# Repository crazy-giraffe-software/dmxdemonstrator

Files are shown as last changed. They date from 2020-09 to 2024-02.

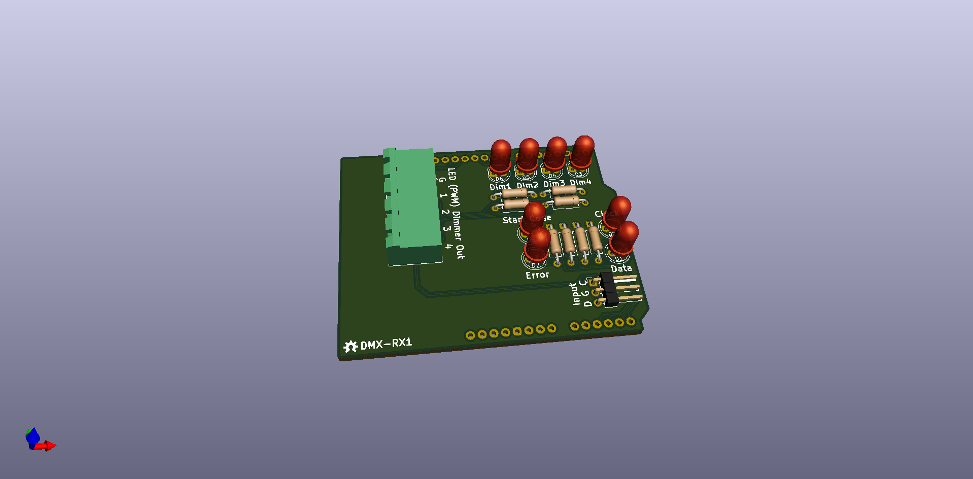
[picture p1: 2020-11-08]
hardware/receiver/receiver.png

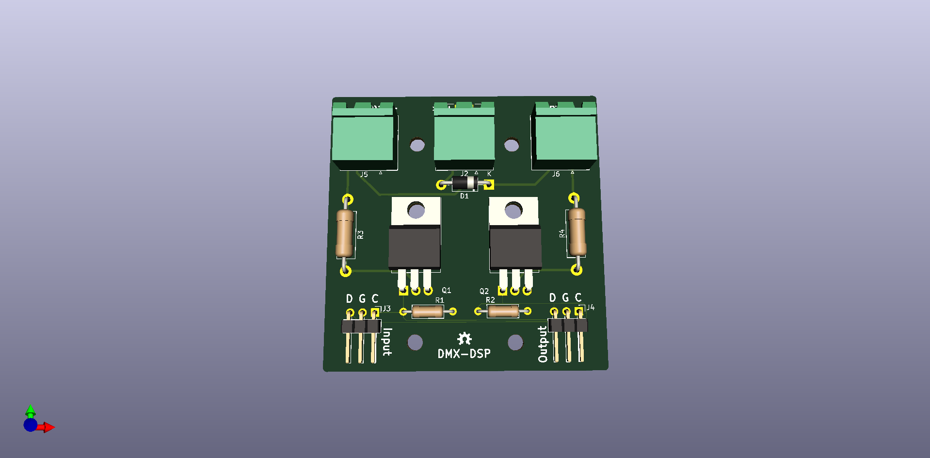
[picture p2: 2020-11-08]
hardware/display-pro/display-pro.png

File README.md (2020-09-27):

# DMX Demonstrator

## Background

When I was in grad school, I was challenged by my technical theater professor to create a device to demonstrate DMX. What we devised was a transmitter receiver pair with 4 controls and 4 dimmers and the pair was linked by a three-wire cable. The transmitter had a fixed clock that could run at reasonable fast, xxkHz, and a variable clock that could be adjusted down to 0.5 hZ. By switching back and forth, you could toggle between "real-time" updates and a slow pace that can be used to see each bit on the wire. We then built a lecture around how the data was digitized, serialized, de-serialized, and converted back to analog to control the dimmers.

The device was built and did function even though it failed to follow a number of best engineering practices. At that time, we didn't have [GitHub](https://github.com/) and [Tindie](https://www.tindie.com/) so sharing the project was by word-of-mouth and email; yes, we did have [email](https://en.wikipedia.org/wiki/Email). Only one other group considered building a replica but alas they never did. The device was built only once and transported to a USITT conference in Las Vegas, where the EPROM failed and we had nothing to show except a presentation. Only a handful of students at my school ever got to see it function.

That was 25 years ago. For it's anniversary, I've decided to revive the project and build 2 new implementations. The first is based on Arduino for a cheap but functional version of the project that is unlikely to fail or break the bank. The second is an updated recreation of the original using today's available hardware but without deviating from the original TTL-based design, i.e. no microprocessors or microcontrollers. I'll admit this last one is really just for me because I love designing electronics, drawing schematics, laying out PCBs, and assembling electronics.

## Hardware

In the hardware folder, you'll find a series of designs:

- transmitter - An arduino-based transmitter.
- receiver - An arduino-based receiver.
- control-pro - A controller built to work with either transmitter or transmitter-pro.
- display-pro - An external large-format display for data and clock signals.

## Firmware/Software

As you would expect, the Arduino-based version is implemented mostly in software. The Sketch files for both transmitter and receiver are in the software folder and ready to upload to an Arduino UNO R3. The sketch and hardware will likely work with any Arduino-compatible board.

## Monitoring

All informational output is sent to via the serial port for easy display on a computer. However, the clock and serial data are displayed via LEDs to visualize the serial data.

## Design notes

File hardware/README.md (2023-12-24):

# DMX Demonstrator Hardware

## Overview

The DMX Demonstrator hardware folder contains various transmitters, receivers, and modules which all for the control of brightness of 4 channels of dimming.

## Status

Each hardware folder will contain a readme explaining the details of the component and it's status. The following is a definition of some common status:

- 

The _verified_ badge indicates that the component has been built and tested for use with the DMX Demonstrator family and is safe to build.

- 

The _testing_ badge indicates that the component has completed the design and prototype phase and being verified for use with the DMX Demonstrator family. It usually is assigned to a component revision for which the previous version is _verified_.

- 

The _prototype_ badge indicates that the component has completed the design phase and is being built and tested for use with the DMX Demonstrator family.

- 

The _design_ badge indicates that the component is still being design. has completed the design phase.

## Compatibility

For the components which connect to an Arduino, the readme provides a list of known compatible Arduino platforms. The DMX Demonstrator family will likely work with most Arduino boards, real or clones, but if you are having an
[issue](https://github.com/crazy-giraffe-software/dmxdemonstrator/issues) with a particular board, open an issue to ask for verification. Please provide as much detail on the board and where is was obtained as possible.
Most compatibility issues are resolved by updating the software and do not require hardware revisions.

The following is a definition of some compatibilities:

- 

The _verified_ badge indicates that the component has been built and tested for the specific Arduino board.

- 

The _testing_ badge indicates that the component is being tested to determine if it is compatible with the specific Arduino board.

- 

The _research_ badge indicates that the component is being researched to determine if it is compatible with the specific Arduino board.

- 

The _incompatible_ badge indicates that the component is not compatible for the specific Arduino board.

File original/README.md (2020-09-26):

# DMX Demonstrator

## Background

When I was in grad school, I was challenged by my technical theater professor to create a device to demonstrate DMX. What we devised was a transmitter receiver pair with 4 controls and 4 dimmers and the pair was linked by a three-wire cable. The transmitter had a fixed clock that could run at reasonable fast, xxkHz, and a variable clock that could be adjusted down to 0.5 hZ. By switching back and forth, you could toggle between "real-time" updates and a slow pace that can be used to see each bit on the wire. We then built a lecture around how the data was digitized, serialized, de-serialized, and converted back to analog to control the dimmers.

The device was built and did function even though it failed to follow a number of best engineering practices. At that time, we didn't have GitHub and Tindie so sharing the project was by word-of-mouth and email; yes, we did have email. Only one other group considered building a replica but alas they never did. The device was built only once and transported to a USITT conference in Las Vegas, where the EPROM failed and we had nothing to show except a presentation. Only a handful of students at my school ever got to see it function.

That was 25 years ago. For it's anniversary, I've decided to revive the project and build 2 new implementations. The first is based on Arduino for a cheap but functional version of the project that is unlikely to fail or break the bank. The second is an updated recreation of the original using today's available hardware but without deviating from the original TTL-based design, i.e. no microprocessors or microcontrollers. I'll admit this last one is really just for me because I love designing electronics, drawing schematics, laying out PCBs, and assembling electronics.

## Artifacts

These are the original digital artifacts we created in 1994 for the DMX Demonstrator. The are preserved here for posterity.

The schematics were original drawn in Autocad but the files have been lost. The paper copy was not lost, the PDFs are a scan of those documents.

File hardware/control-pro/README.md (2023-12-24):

# DMX Demonstrator Control Pro  (DMX-CP*)



## Overview

The Control Pro is built to work with either transmitter or transmitter-retro. When used with an Arduino, an additional board, the Transmitter IO Interface (DMX-TX2), is required to connect the Control Pro to the Arduino. The transmitter software automatically detects whether DMX-TX1, the standard transmitter, or DMX-TX2, the Transmitter IO Interface, is connected.

The Control Pro is designed so that a series of components are sandwiched between 2 circuit boards. As a result, the heights of the components are fairly sensitive in order to make things line up nicely. The DMX-CPDB and DMX-CPCB boards contains all the parts and are the bottom of the sandwich, the DMX-CPDF and DMX-CPCB are the faceplate, i.e. the tops of the sandwich. If you are wondering why there are 4 total boards, see _PCB->Quality vs Price_ below.

## Online parts list

Sparkfun offers some, but not all, of the components required for the Control Pro. For the parts they can supply, you can find a parts lists [here](https://www.sparkfun.com/wish_lists/160543).

Additionally, you'll need some parts from the common parts lists as well. You can find the common parts list [here](https://www.sparkfun.com/wish_lists/160406). The rainbow LED pack include 2 sets of LED so if you are building more than 2 transmitters or receivers, make sure to buy 1 pack for every 2 transmitters/receivers.

## PCB

You can order the PCBs from [OHS Park](https://oshpark.com/):

- [Clock Control: DMX-CPCB, Rev 1.3](https://oshpark.com/shared_projects/llBuRZd8)
- [Clock Faceplate: DMX-CPCF, Rev 1.3](https://oshpark.com/shared_projects/S9LARHyr)
- [Dimmer Control: DMX-CPDB, Rev 1.3](https://oshpark.com/shared_projects/O76YiRT8)
- [Dimmer Faceplate: DMX-CPDF, Rev 1.3](https://oshpark.com/shared_projects/bZqKigQF)

### Quality vs Price

While it is counterintuitive (and in some cases wrong), splitting the clock controls and dimmer controls on different boards reduces cost. Many PCB manufacturers offer a fixed cost for board smaller than a certain size. These boards are 100mm x 100mm, which is standard max size for many low-cost board manufacturers. Others like OHSPark charge by the square inch and therefore the separate control approach is more expensive. Revision 1.1 was a single set of boards 180mm x 90mm for which OHSPark charges about $250US for 3 copies of both boards. Revision 1.3 is more expensive from OHSPark but can be as cheap as $20US for 5 copies of all 4 boards from cheaper board manufacturers. Yes, there is a quality BIG difference between those prices but the cheaper board will work just fine.

OHSPark offers really great quality at great prices, they are easy to work with, manufacture 100% in the US, and their support is excellent. I use OHSPark for most things I build, expect when the cost is super high. Lower cost boards can be had but if you specify the same quality board OHSPark offers, you will find OHSPark to be competitive. Yes, the links above are for the more expensive OHSPark board for the reason I listed above plus ease of use: You can upload the file directly from Kicad and they can produce a board. Better yet, they will save that board for others to order. They make it so easy to order for a project like this it's silly not to use them.

I offer this opinion freely and do not receive any compensation from OHSPark.

## Parts

The Control Pro is designed so that a series of components are sandwiched between 2 circuit boards. As a result, the heights of the components are fairly sensitive in order to make things line up nicely. Here are the parts for which I designed. The DMX-CPDB and DMX-CPCB boards contains all the parts and are the bottom of the sandwich, the DMX-CPDF and DMX-CPCB are the faceplate, i.e. the tops of the sandwich. If you are wondering why there are 4 total boards, see _PCB->Quality vs Price_.

### Slider Potentiometers

Getting a potentiometer and knob combo that would work with the rest of the components was probably the hardest part of part selection.
I had initially ordered some 60mm 10k sliders from SparkFun with matching knobs and they measures about 25mm from the bottom of the
part to the bottom of the knob, which is way too tall for the other components! I landed on a combination of Bourns PTA Series
sliders with an knob available from Sparkfun (and others). During this process, I opted for a 45mm travel to keep the board smaller/cheaper
while still offering good mechanical resolution. The specific parts I designed for are:

- Dimmer Sliders: Bournes PTA4543-2015DPB103, quantity 4:
  - [Data sheet](https://www.mouser.com/datasheet/2/54/pta-778345.pdf)
  - [Digikey PTA4543-2015DPB103-ND](https://www.digikey.com/products/en?keywords=PTA4543-2015DPB103-ND)
  - [Mouser 652-PTA45432015DPB10](https://www.mouser.com/ProductDetail/Bourns/PTA4543-2015DPB103?qs=U%2FacTlguYxbmwS%2FtylIWJw%3D%3D)
- Knobs: Eagle 450-3051, quantity 4:
  - [Datasheet](https://www.mouser.com/datasheet/2/209/EPD-200140-1171100.pdf)
  - [Mouser 450-3051](https://www.mouser.com/ProductDetail/Eagle-Plastic-Devices/450-3051?qs=hTs5c5NaUrTeABpuQnP9ug%3D%3D)
  - [Sparkfun COM-09120](https://www.sparkfun.com/products/9120) - Included in online parts list

### Toggle Switches

Just about any miniature toggle switch will do, many manufacturers make a switch in a similar size. I specifically used the E-Switch Series 100 Miniature Toggle Switches, specifically:

- Clock Speed: E-Switch 100DP3T1B1M1QEH, quantity 1:
  - [Datasheet](https://sten-eswitch-13110800-production.s3.amazonaws.com/system/asset/product_line/data_sheet/129/100.pdf)
  - [Digikey EG2413-ND](https://www.digikey.com/products/en?keywords=100DP3T1B1M1QEH)
  - [Mouser 612-100-H1111](https://www.mouser.com/ProductDetail/E-Switch/100DP3T1B1M1QEH?qs=g8hxKYs5b3yy1L1GZVrx5w%3D%3D)
- Clock Step: E-Switch 100SP2T1B1M1QEH, quantity 1:
  - [Datasheet](https://sten-eswitch-13110800-production.s3.amazonaws.com/system/asset/product_line/data_sheet/129/100.pdf)
  - [Digikey EG2373-ND](https://www.digikey.com/product-detail/en/e-switch/100SP2T1B1M1QEH/EG2373-ND/378842)
  - [Mouser 612-100-B1111](https://www.mouser.com/ProductDetail/E-Switch/100SP2T1B1M1QEH?qs=HKd%2Fp3M7KlWCZ%252BGqDexPKQ%3D%3D)

### Rotary Potentiometer

With the toggle and sliders determining the basic component height, I searched for a rotary potentiometer to fit the requirements and once again found a Bournes product. It has a 6mm "D"/flattened shaft so just about any 6mm flattened shaft knob will work but something with a set screw will help secure it. I did not find a great choice at Digikey or Mouser but Amazon and EBay has a ton of choices, designed for use with musical instruments.

Sparkfun offers a potentiometer and knob that make an excellent choice. The knob even [goes to 11](https://en.wikipedia.org/wiki/Up_to_eleven). The Sparkfun part is not a Bournes PTV09A-4030F-B103 but it's the same physical size and resistance.

Specifically:

- Clock Speed Control: Bournes PTV09A-4030F-B103, quantity 1:
  - [Datasheet](https://www.bourns.com/docs/Product-Datasheets/PTV09.pdf)
  - [Digikey 118-PTV09A-4030F-B103-ND](https://www.digikey.com/en/products/detail/bourns-inc/PTV09A-4030F-B103/3820581)
  - [Mouser 652-PTV09A-4030FB103](https://www.mouser.com/ProductDetail/Bourns/PTV09A-4030F-B103?qs=Zq5ylnUbLm4pfFuWlwC80Q%3D%3D)
  - [Sparkfun COM-09288](https://www.sparkfun.com/products/9288) - Included in online parts list
- Knob, quantity 1:
  - [Sparkfun COM-11951](https://www.sparkfun.com/products/11951) - Included in online parts list

### LEDs and Spacers

Luckily most LEDs have leads long enough to make it from the bottom to top board so nothing special is needed here, just make sure to have 17.5mm of lead length. Most LEDs have a voltage and current range near 2v and 10ma and the design will accommodate variances easily.

I like the [Sparkfun rainbow LED Kit](https://www.sparkfun.com/products/12903) which gives you 2 each of 6 colors, letting you match colors for dimmers 1-4, data and clock on both the transmitter and receiver without re-using colors. This LED kit is included in the common parts list. However, they will need a bit of added stability, which is where an LED spacer is needed. Something between 16mm and 17mm will work fine. Here's a suitable one:

- LED: T1 3/4 or 5mm Led in various colors, quantity 1:
  - [Sparkfun rainbow LED Kit](https://www.sparkfun.com/products/12903) - Included in common online parts list
- LED Spacer: Würth 705820170, quantity 8:
  - [Data sheet](https://www.we-online.de/katalog/datasheet/705820xxx_overview.pdf)
  - [Digikey 732-11617-ND](https://www.digikey.com/product-detail/en/w%C3%BCrth-elektronik/705820170/732-11617-ND/7681962)
  - [Mouser 710-705820170](https://www.mouser.com/ProductDetail/Wurth-Elektronik/705820170?qs=wr8lucFkNMUaK6Cwpwjx5Q%3D%3D)

The rainbow LED kit includes 1 red and one green LED for the data and clock. However, there are 3 sets of data and clock LEDs on the three boards. Also, there are 2 LEDs to verify detection of the Control Pro, one on each board. These LEDs are included in the Control Pro online parts list [here](https://www.sparkfun.com/wish_lists/160543).

### Cable and Connector

To connect the controller to the transmitter, you'll need some cables and connectors. Ribbon cable makes a nice choice for this and you can find pre-made ribbon cable assemblies on Amazon and EBay easily. I've designed for a 16 pin cable. I recommend shrouded headers for connecting to PCBs and it ensures you don't plug the cable in backwards. Here are some suitable headers:

- Header: Würth Elektronik 61201621721, quantity 4:
  - [Datasheet](https://www.we-online.com/components/products/datasheet/61201621721.pdf)
  - [Digikey 732-2099-ND](https://www.digikey.com/en/products/detail/w%C3%BCrth-elektronik/61201621721/2060595)
  - [Mouser 710-61201621721](https://www.mouser.com/ProductDetail/Wurth-Elektronik/61201621721?qs=ZtY9WdtwX56ShT0tAQh3qw%3D%3D)
- Header: 3M 30316-6002HB, quantity 1:
  - [Datasheet](https://www.mouser.com/datasheet/2/1/78-5100-0818-4_D-221281.pdf)
  - [Digikey 3M11931-ND](https://www.digikey.com/products/en?keywords=30316-6002HB)
  - [Mouser 517-30316-6002](https://www.mouser.com/ProductDetail/3M-Electronic-Solutions-Division/30316-6002HB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)
- Cable, quantity 2:
  - [Amazon: Antrader 30CM 16-Pin IDC Connector Flat Ribbon Cable](https://smile.amazon.com/dp/B07FZWH9S6/ref=cm_sw_em_r_mt_dp_n0-BFbMSE9MJX )

### Standoff and Feet

Finally, you'll need some standoffs to hold the boards together and some feet to avoid the bottom PCB from dragging across the table. You can adjust the screw size and add some washers or plexiglass if you like to create a smooth bottom surface. The standoffs should be 18mm in length and the boards are designed for an M3 screw. Amazon and EBay offer tons of options. I even found [purple ones on EBay](https://www.ebay.com/itm/M3-Aluminum-Alloy-Female-Hex-Hexagon-Threaded-Bush-Sleeve-Standoff-Pillar-Spacer/174350100853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).

- Standoff: Keystone 24476/24446/25531 (M3, 18mm length), quantity 4:
  - [Digikey 36-24476-ND, stainless steel](https://www.digikey.com/product-detail/en/keystone-electronics/24476/36-24476-ND/1532963)
  - [Digikey 36-24446-ND, aluminum](https://www.digikey.com/product-detail/en/keystone-electronics/24446/36-24446-ND/1532945)
  - [Digikey 36-25513-ND, nylon](https://www.digikey.com/product-detail/en/keystone-electronics/25513/36-25513-ND/1532191)
  - [Mouser 534-24476, stainless steel](https://www.mouser.com/ProductDetail/Keystone-Electronics/24476?qs=UWqYQ%2F2cZWsNG8Fm%2FRkk0Q%3D%3D)
  - [Mouser 534-24436, aluminum](https://www.mouser.com/ProductDetail/Keystone-Electronics/24436?qs=UWqYQ%2F2cZWv7%252B7DoeljlhQ%3D%3D)
  - [Mouser 534-25513, nylon](https://www.mouser.com/ProductDetail/Keystone-Electronics/25513?qs=UWqYQ%2F2cZWtItbFiR1P%2F3w%3D%3D)
  - [Ebay M3 Aluminum Alloy Red, Blue, Purple, Black, Gold, Silver](https://www.ebay.com/itm/M3-Aluminum-Alloy-Female-Hex-Hexagon-Threaded-Bush-Sleeve-Standoff-Pillar-Spacer/174350100853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)

### Passive components

The Control Pro has a few passive listed on the schematic and are included in the common parts list [here](https://www.sparkfun.com/wish_lists/160406).

## Version History

### Rev 1.3

- Add copper pours to both faceplates
- No changes to control boards.

### Rev 1.2

#### DMX-CPC*

- Split clock controls out to its own PCB
- Added 2nd 16 pin connector to daisy chain with DMX-CPD*.
- Switched to horizontal 16 pin connectors since vertical was too tall with a cable plugged in
- Swapped the clock speed and step switches to match the order on the TX1
- Swapped the data and clock LEDs to match the order on the TX1

#### DMX-CPD*

- Split dimmer controls out to its own PCB
- Added 2nd 16 pin connector to daisy chain with DMX-CPC*.
- Switched to horizontal 16 pin connectors since vertical was too tall with a cable plugged in

### Rev 1.1

#### DMX-CPB

- Added rounded corners.

#### DMX-CPF

- Removed copper from 3rd slider slot by enlarging slot width.
- Added rounded corners.

### Rev 1.0

- Initial draft, all boards.

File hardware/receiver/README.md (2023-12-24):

# DMX Demonstrator Receiver (DMX-RX1)



## Status : Testing

## Overview

The Receiver is an [Arduino](https://www.arduino.cc/) Shield which accepts the 3-wire data/clock signal from the Transmitter (DMX-TX1) and decodes the data stream to control the brightness of 4 LEDs.

## Online parts list

Sparkfun offers all of the components required for the receiver. You can find a parts lists [here](https://www.sparkfun.com/wish_lists/160542).

Additionally, you'll need some parts from the common parts lists as well. You can find the common parts list [here](https://www.sparkfun.com/wish_lists/160406). The rainbow LED pack include 2 sets of LED so if you are building more than 2 transmitters or receivers, make sure to buy 1 pack for every 2 transmitters and receivers.

## PCB

You can order the PCB from [OHS Park](https://oshpark.com/):

- [DMX-RX1, Rev 1.3](https://oshpark.com/shared_projects/b6uh6OMa).

### Quality vs Price

OHSPark offers really great quality at great prices, they are easy to work with, manufacture 100% in the US, and their support is excellent. I use OHSPark for almost everything I build, expect when the cost is super high. Lower cost boards can be had but if you spec the same quality board OHSPark offers at those places, you will find OHSPark to be competitive. Yes, the links above are for the more expensive OHSPark board for the reason I listed above plus ease of use: You can upload the file directly from Kicad and they can produce a board. Better yet, they will save that board for others to order. They make it so easy to order for a project like this it's silly not to use them.

I offer this opinion freely and do not receive any compensation from OHSPark.

- ## Compatibility

 The DMX-RX1 is compatible with the following Arduino platforms:



- Arduino Uno R3: Hardware Revision 1.1+, Software Version 1.1+
- Arduino Leonardo: Hardware Revision 1.1+, Software Version  1.1+
- Arduino Mega or Mega 2560: Hardware Revision 1.1+, Software Version 1.2+

## Version History

### Rev 1.3

- Remove PWM connector

### Rev 1.2

- Moved clock LED to avoid Arduino ICSP connector.
- Add RXCLK to D9 connection for Leonardo PCINT5.

### Rev 1.1

- Fixed shield footprint
- Added error and start code LEDs.
- Added Fcu power plane
- Redid Fcu layout
- Added rounded corners

### Rev 1.0

- Initial draft

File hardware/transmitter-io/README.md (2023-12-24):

# DMX Demonstrator Transmitter IO Interface (DMX-TX2)



## Overview

The Transmitter IO Interface is an [Arduino](https://www.arduino.cc/) Shield which provides the 3-wire data/clock signal to the Receiver (DMX-RX1) and encode the data stream to control the brightness of 4 LEDs using the Control Pro (DMX-CP*).

## Online parts list

Sparkfun offers some, but not all, of the components required for the Control Pro. For the parts they can supply, you can find a parts lists [here](https://www.sparkfun.com/wish_lists/160543).

Additionally, you'll need some parts from the common parts lists as well. You can find the common parts list [here](https://www.sparkfun.com/wish_lists/160406).

## PCB

You can order the PCBs from [OHS Park](https://oshpark.com/):

- [DMX-TX2, Rev 1.3](https://oshpark.com/shared_projects/mKdzHGgN)

## Compatibility

 The DMX-TX2 is compatible with the following Arduino platforms:



- Arduino Uno R3: Hardware Revision 1.2+, Software Version 1.2+
- Arduino Leonardo: Hardware Revision 1.2+, Software Version 1.2+
- Arduino Mega or Mega 2560: Hardware Revision 1.2+, Software Version 1.2+

## Version History

### Rev 1.3

- Switch to 74LS07 for Led driver
- Add pullup resistor for discovery
- Add silkscreen values

### Rev 1.2

- Added buffer to drive LEDs
- Added decoupling capacitors
- Fixed dimmer traces on PCB
- Add IO connector
- Moved to it's own folder since it's not dedicated to the control pro.

### Rev 1.1

- Added buffer to drive LEDs
- Added decoupling capacitors
- Fixed dimmer traces on PCB

### Rev 1.0

- Initial draft

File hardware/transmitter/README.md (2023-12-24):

# DMX Demonstrator Transmitter (DMX-TX1)



## Overview

The Transmitter is an [Arduino](https://www.arduino.cc/) Shield which provides the 3-wire data/clock signal to the Receiver (DMX-RX1) and encode the data stream to control the brightness of 4 LEDs.

## Online parts list

Sparkfun offers all of the components required for the transmitter. You can find a parts lists [here](https://www.sparkfun.com/wish_lists/160541).

Additionally, you'll need some parts from the common parts lists as well. You can find the common parts list [here](https://www.sparkfun.com/wish_lists/160406). The rainbow LED pack include 2 sets of LED so if you are building more than 2 transmitters or receivers, make sure to buy 1 pack for every 2 transmitters and receivers.

Note: The rotary potentiometer offered by sparkfun stands a total of 30mm from the board. It's a little tall but perfectly functional, not to mention the sell everything else. However, you can opt for a short potentiometer, the Bourns PTV09A-4020F-B103 is a great choice:

- [DataSheet](https://www.bourns.com/docs/Product-Datasheets/PTV09.pdf)
- [Digikey PTV09A-4020F-B103-ND](https://www.digikey.com/products/en?keywords=PTV09A-4020F-B103)
- [Mouser 652-PTV09A-4020FB103](https://www.mouser.com/ProductDetail/Bourns/PTV09A-4020F-B103?qs=Qzws7J6gxqx9VaKCiVoniw%3D%3D)

## PCB

You can order the PCB from [OHS Park](https://oshpark.com/):

- [DMX-TX1, Rev 1.3](https://oshpark.com/shared_projects/BYd66lVx)

### Quality vs Price

OHSPark offers really great quality at great prices, they are easy to work with, manufacture 100% in the US, and their support is excellent. I use OHSPark for almost everything I build, expect when the cost is super high. Lower cost boards can be had but if you spec the same quality board OHSPark offers at those places, you will find OHSPark to be competitive. Yes, the links above are for the more expensive OHSPark board for the reason I listed above plus ease of use: You can upload the file directly from Kicad and they can produce a board. Better yet, they will save that board for others to order. They make it so easy to order for a project like this it's silly not to use them.

I offer this opinion freely and do not receive any compensation from OHSPark.

## Compatibility

 The DMX-TX1 is compatible with the following Arduino platforms:



- Arduino Uno R3: Hardware Revision 1.1+, Software Version 1.1+
- Arduino Leonardo: Hardware Revision 1.1+, Software Version 1.1+
- Arduino Mega or Mega 2560: Hardware Revision 1.1+, Software Version 1.2+

## Revision History

### Rev 1.3

- Improved surface area of power plane

### Rev 1.2

- Moved Clock LED to avoid Arduino ICSP connector.
- Relabeled the clock fast and slow LED connections in the
  schematic to match the board layout.

### Rev 1.1

- Fixed shield footprint
- Added Fcu power plane
- Redid Fcu layout
- Added rounded corners

### Rev 1.0

- Initial draft

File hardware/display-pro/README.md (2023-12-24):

# DMX Demonstrator Display-Pro (DMX-DSP)



## Overview

The display-pro is breakout board designed to intercept the 3-wire data/clock signal from the transmitter to amplify the data and clock signals and drive a larger display intended for a large audience.

It is built to drive an DC output for up to 60v volts so it is compatible with a variety of displays. The parts list has a display and power supply to keep you from having to come up with your own. Feel free to use the recommended option or play around with something else!

## Online parts list

Sparkfun offers all of the components required for the display-pro. You can find a parts lists [here](https://www.sparkfun.com/wish_lists/160583).

If you plan to use something else for the display, you can leave out the Big Dome Buttons, the 12v power supply (you'll likely need something to supply more current anyway). You may also want to consider adding heat sinks, either two of the [PRT-00121](https://www.sparkfun.com/products/121) or [PRT-14340](https://www.sparkfun.com/products/14340) depending on your load.

## PCB

You can order the PCB from [OHS Park](https://oshpark.com/):

- [DMX-DSP, Rev 1.2](https://oshpark.com/shared_projects/f2CQyT9d).

## Version History

### Rev 1.2

- Remove COAX power connector

### Rev 1.1

- Added rounded corners

### Rev 1.0

- Initial draft

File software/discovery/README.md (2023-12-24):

# DMX Demonstrator Discovery Software

## Overview

The discovery software is an Arduino sketch design for use with the both the DMX-RX1, the standard receiver, the DMX-TX1, the standard transmitter, or DMX-TX2, the control-pro adapter. The discovery software automatically detects whether DMX-RX1, DMX-TX1, or DMX-TX2  is connected.

The discovery software also tests the basic functionality of the connected board.

## Compatibility

 The discovery software is compatible with the following Arduino platforms:



- Arduino Uno R3, Version 1.0+
- Arduino Leonardo, Version 1.0+
- Arduino Mega or Mega 2560, Version 1.0+

## Version History

### Rev 1.1

- Fixed detection of DMX-TX2/control-pro.
- Fixed test mode of DMX-TX2/control-pro.

### Rev 1.0

- Initial draft

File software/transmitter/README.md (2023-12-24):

# DMX Demonstrator Transmitter Software

## Overview

The transmitter software is an Arduino sketch design for use with the both the DMX-TX1, the standard transmitter, or DMX-TX2, the control-pro adapter. The transmitter software automatically detects whether DMX-TX1 or DMX-TX2 is connected.

## Compatibility

 The transmitter software is compatible with the following Arduino platforms:



- Arduino Uno R3, Version 1.1+
- Arduino Leonardo, Version 1.1+
- Arduino Mega or Mega 2560, Version 1.2+

## Version History

### Rev 1.2

- Fixed clock mode detection when using control-pro.

### Rev 1.1

- Refactored to capture analog values asynchronously.
- Refactor to add human readable status output.

### Rev 1.0

- Initial draft

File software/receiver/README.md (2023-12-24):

# DMX Demonstrator Receiver Software

## Overview

The receiver software is an Arduino sketch design for use with the both the DMX-RX1, the standard receiver.

## Compatibility

 The receiver software is compatible with the following Arduino platforms:



- Arduino Uno R3,  Version 1.1+
- Arduino Leonardo, Version 1.1+
- Arduino Mega or Mega 2560, Version 1.2+

## Version History

### Rev 1.2

- Added support for Arduino Mega or Mega 2560.

### Rev 1.1

- Refactored to trigger processing based on pin change interrupt.
- Refactor to add human readable status output.

### Rev 1.0

- Initial draft

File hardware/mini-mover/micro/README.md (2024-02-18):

The micro is based on micro servo brackets available on amazon.

3W led with heatsink and fan
external CC drivers x 4 + fan + temp sensor
2 ch PWM for servo pan/tilt

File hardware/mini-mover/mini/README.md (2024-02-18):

The mini is based on standard servo brackets available on amazon.

10w head with heatsink and fan
external CC drivers x 3 + fan + temp sensor
2 ch PWM for servo pan/tilt

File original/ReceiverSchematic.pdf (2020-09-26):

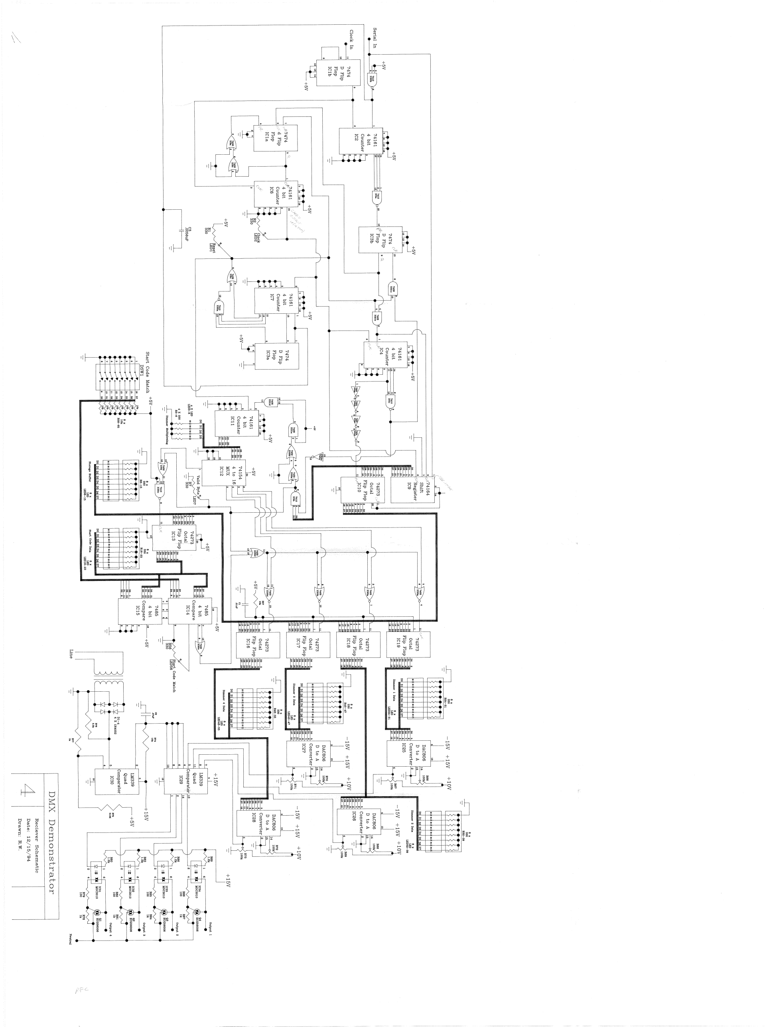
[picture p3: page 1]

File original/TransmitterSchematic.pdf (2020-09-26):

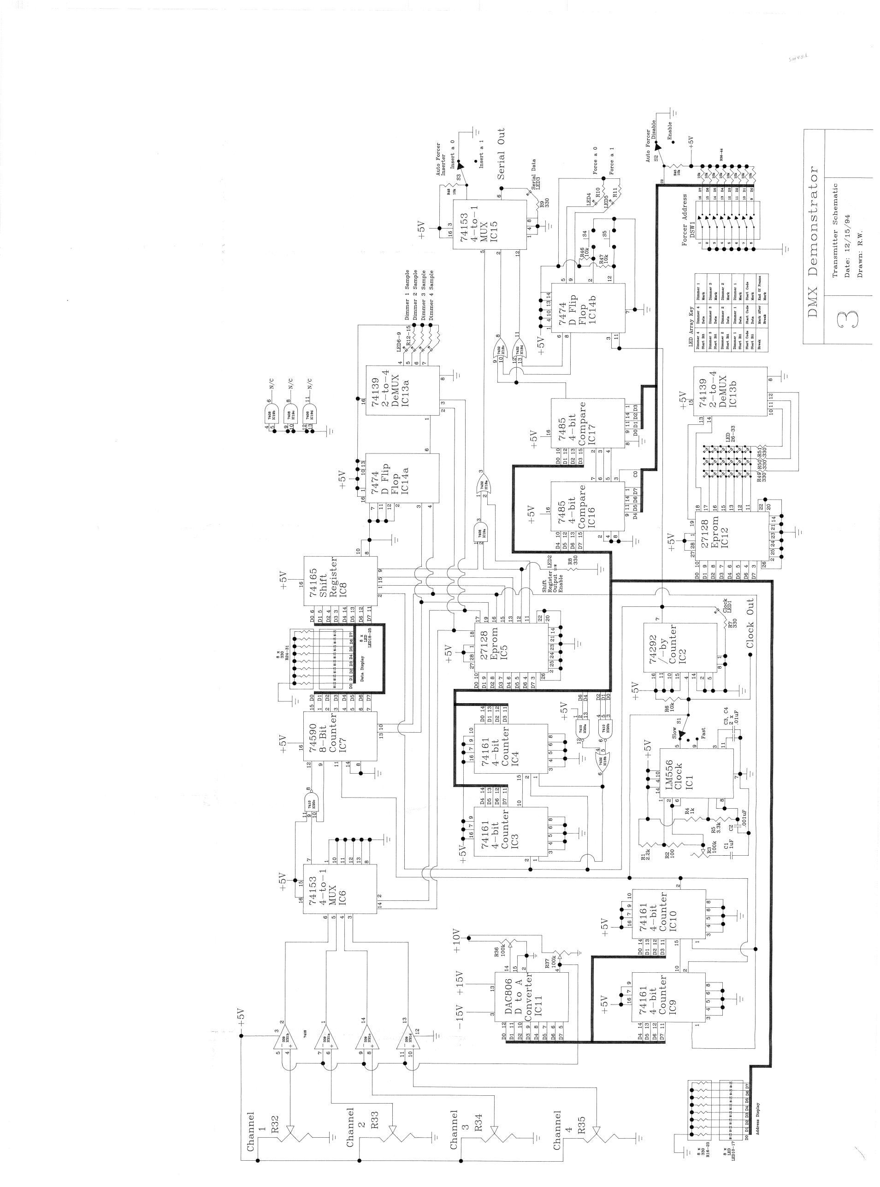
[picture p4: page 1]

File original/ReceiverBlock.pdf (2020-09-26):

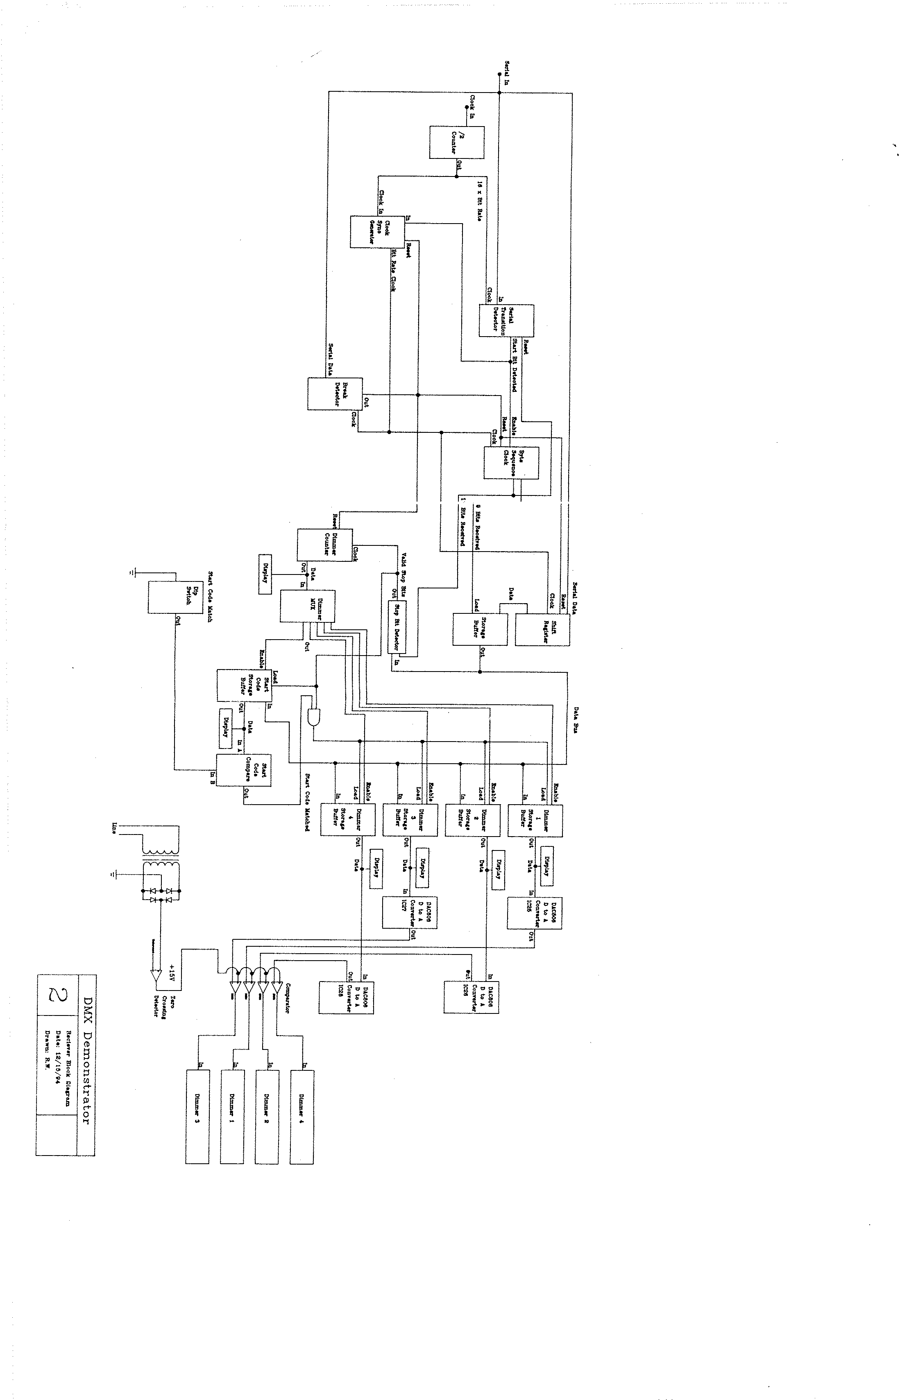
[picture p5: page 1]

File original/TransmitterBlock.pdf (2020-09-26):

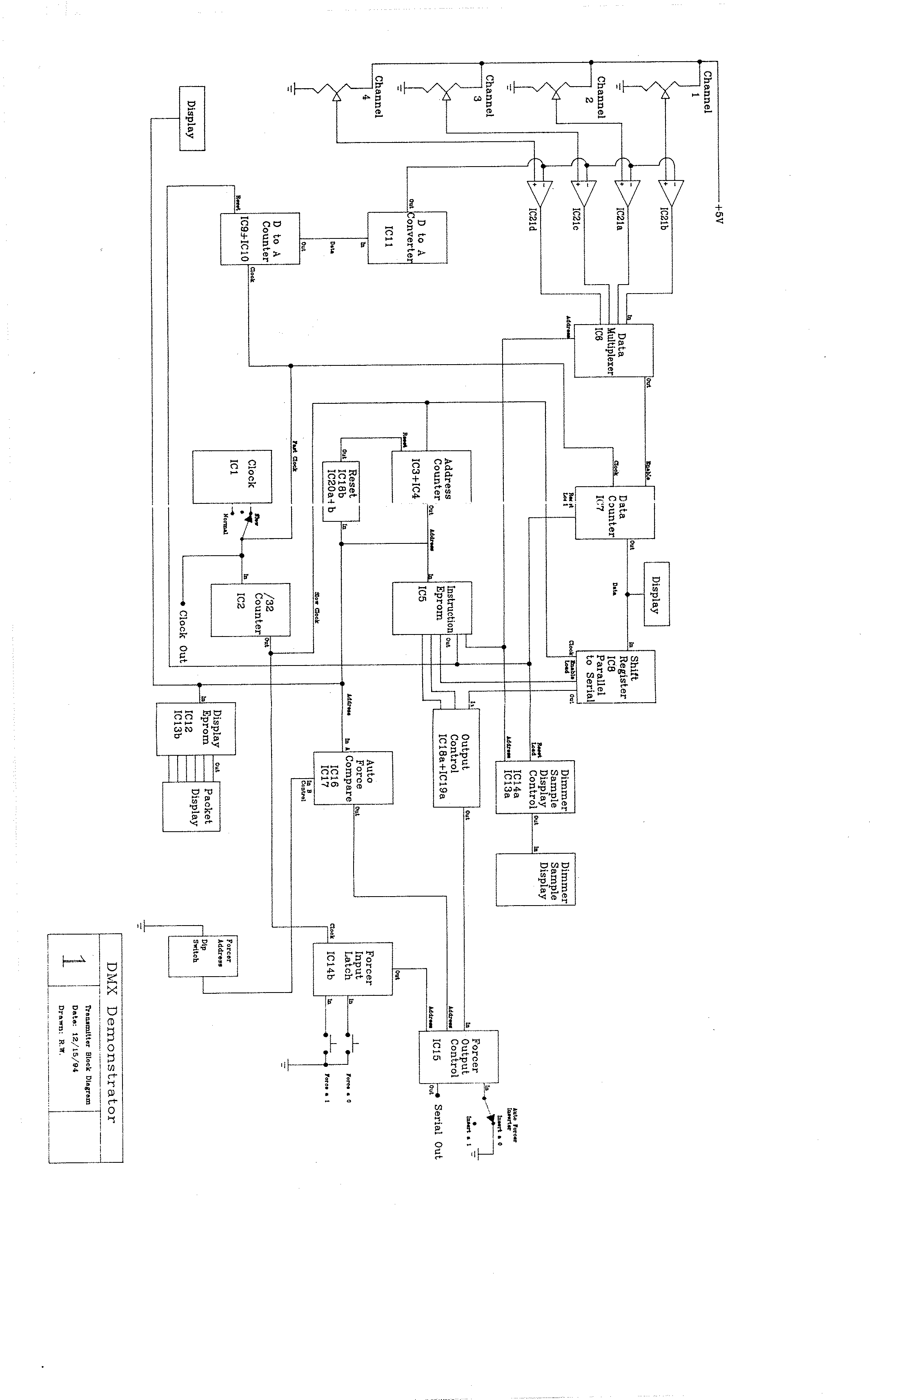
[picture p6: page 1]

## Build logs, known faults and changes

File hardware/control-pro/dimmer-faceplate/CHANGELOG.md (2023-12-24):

# DMX Demonstrator Control-Pro Faceplate (DMX-CPF)



## Changes

### 1.1

Removed copper from 3rd slider slot by enlarging slot width.
Added rounded corners.

### 1.0

Initial version.

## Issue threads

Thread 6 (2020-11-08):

Arduino footprint are backwards

SparkyBobo255, 2020-11-08:
The Arduino footprints used the Kicad R3 footprints, which are intentionally backwards. As a result, these boards cannot connect to Arduinos as a shield.

Closed 2020-11-08.

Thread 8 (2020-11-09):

Sparkfun powerjack does not fit the display pro

SparkyBobo255, 2020-11-09:
The existing footprint for the display-pro power jack does not fit the Sparkfun connector. The Spakrfun connector footprint conflicts with the 2 pin connector foot print.

Closed 2020-11-09.

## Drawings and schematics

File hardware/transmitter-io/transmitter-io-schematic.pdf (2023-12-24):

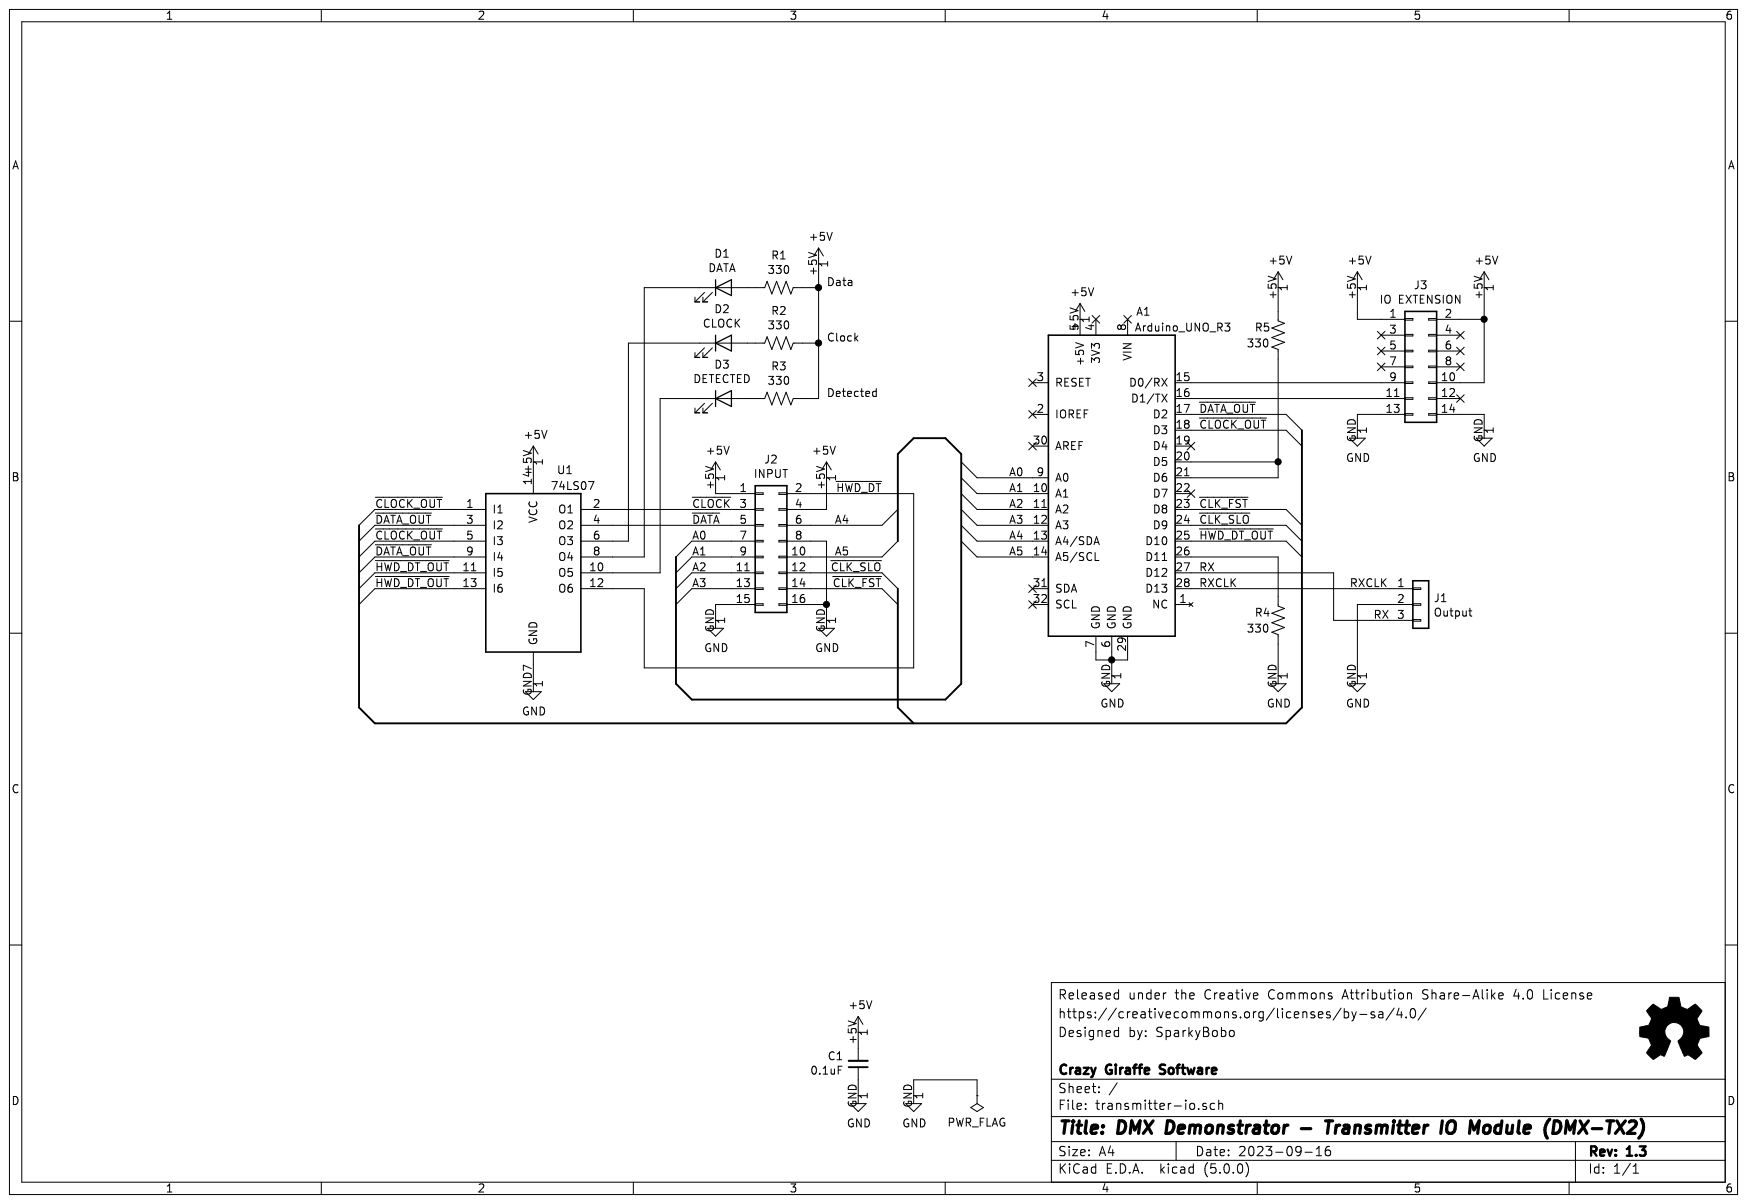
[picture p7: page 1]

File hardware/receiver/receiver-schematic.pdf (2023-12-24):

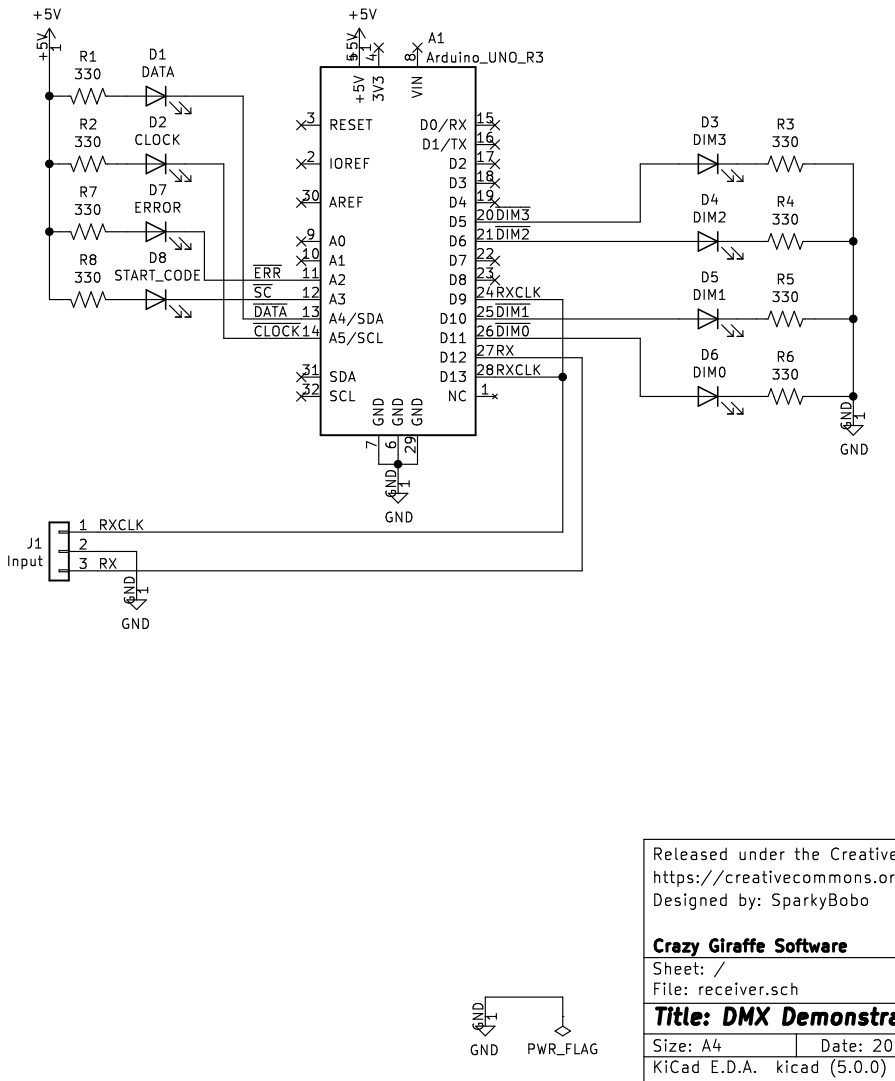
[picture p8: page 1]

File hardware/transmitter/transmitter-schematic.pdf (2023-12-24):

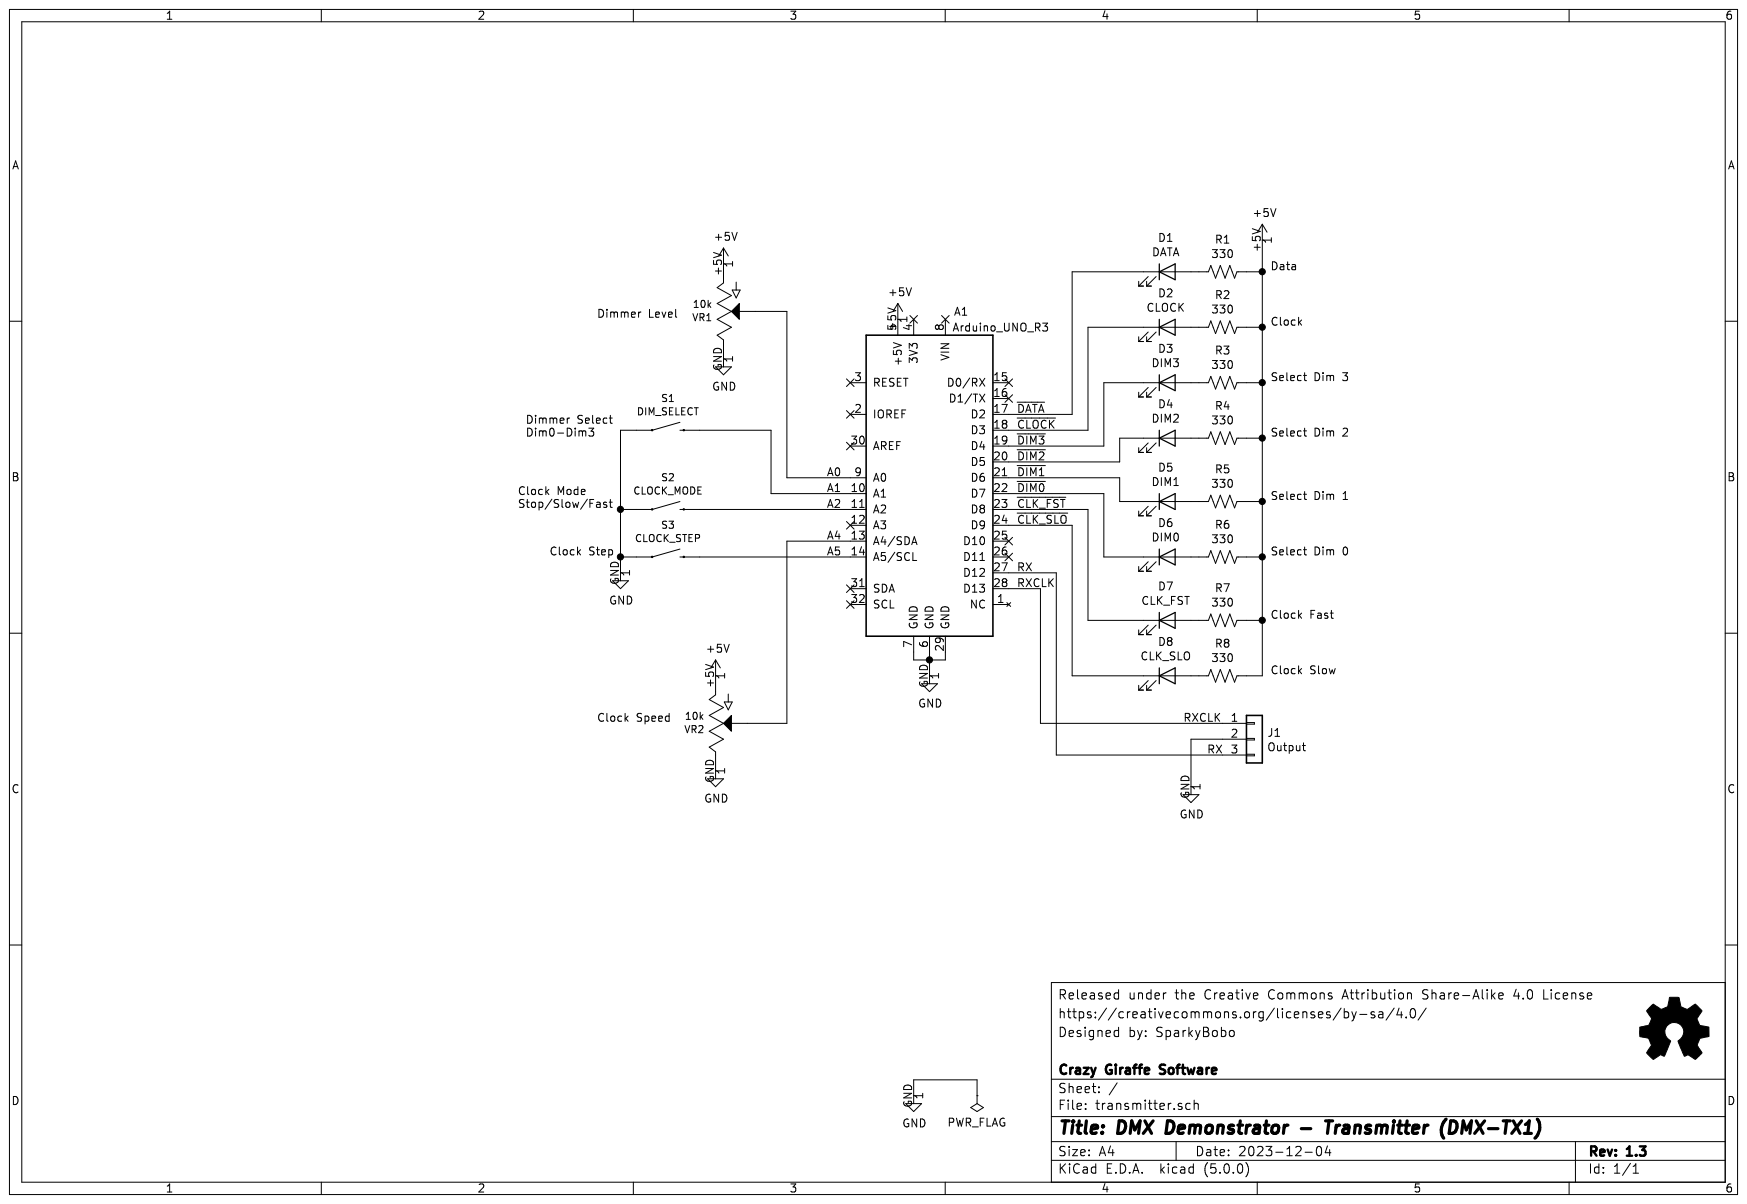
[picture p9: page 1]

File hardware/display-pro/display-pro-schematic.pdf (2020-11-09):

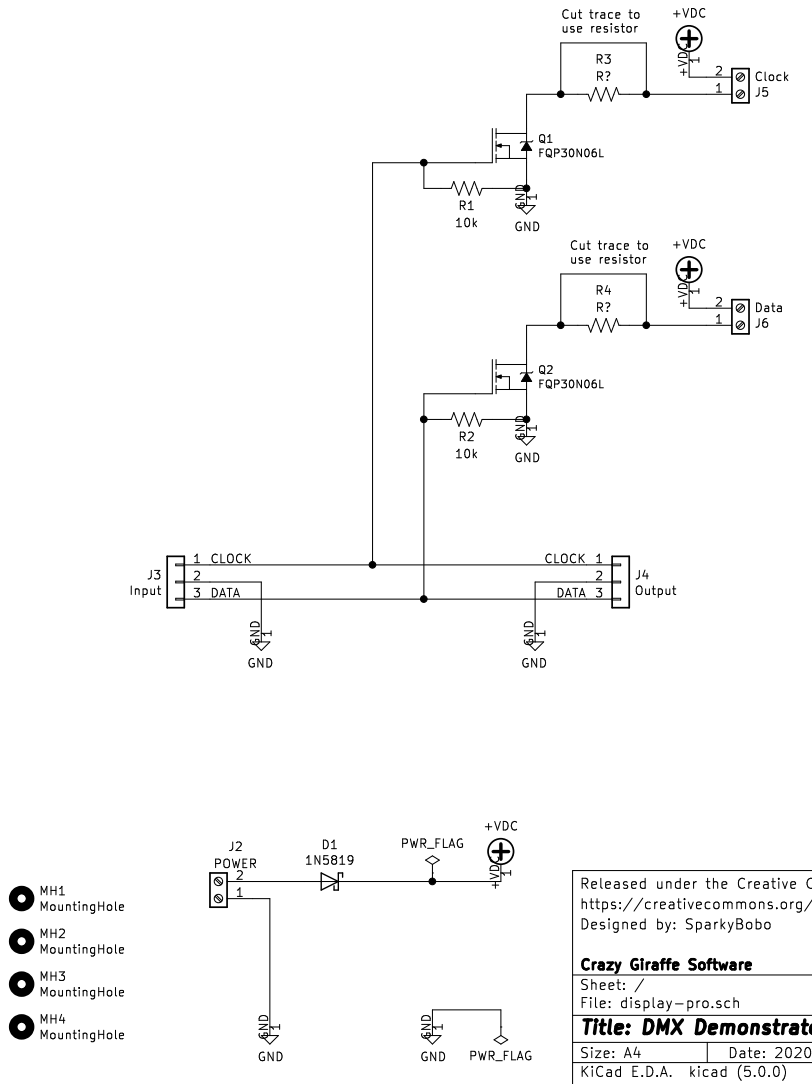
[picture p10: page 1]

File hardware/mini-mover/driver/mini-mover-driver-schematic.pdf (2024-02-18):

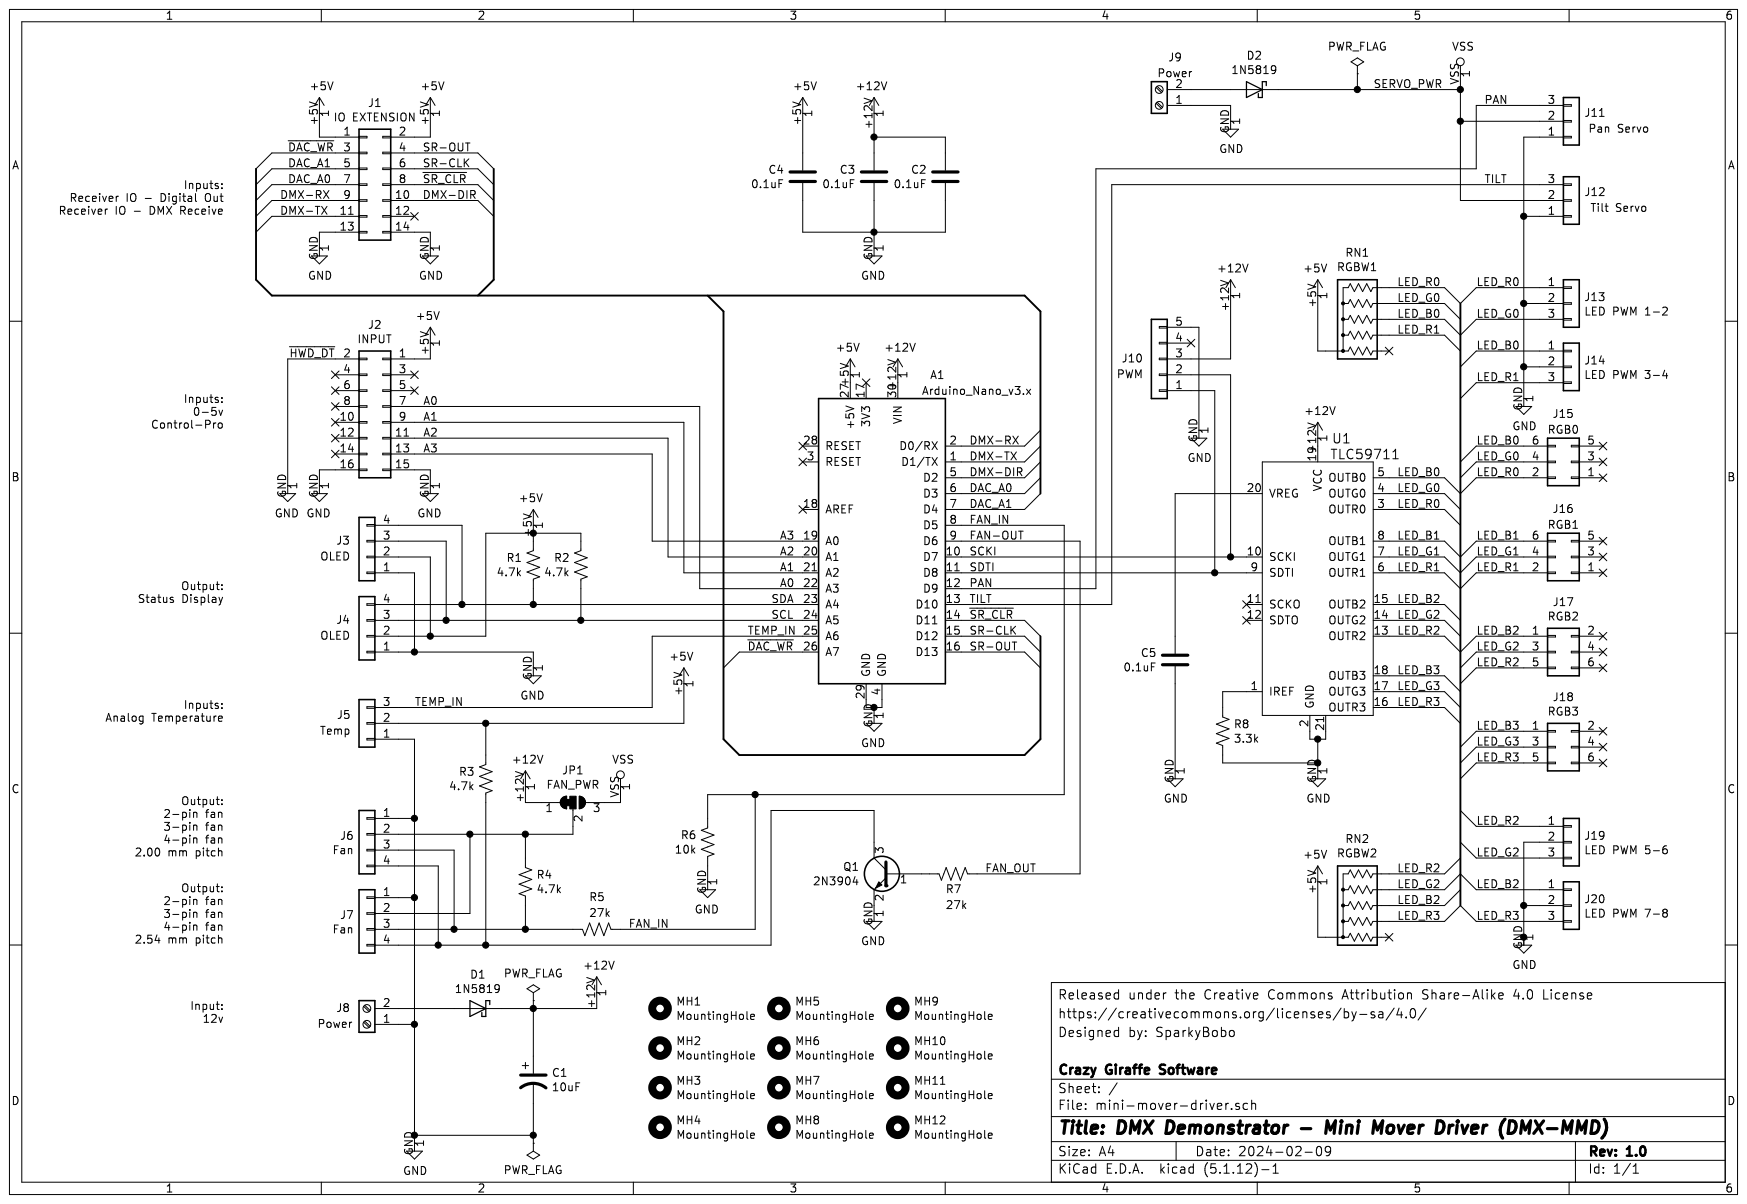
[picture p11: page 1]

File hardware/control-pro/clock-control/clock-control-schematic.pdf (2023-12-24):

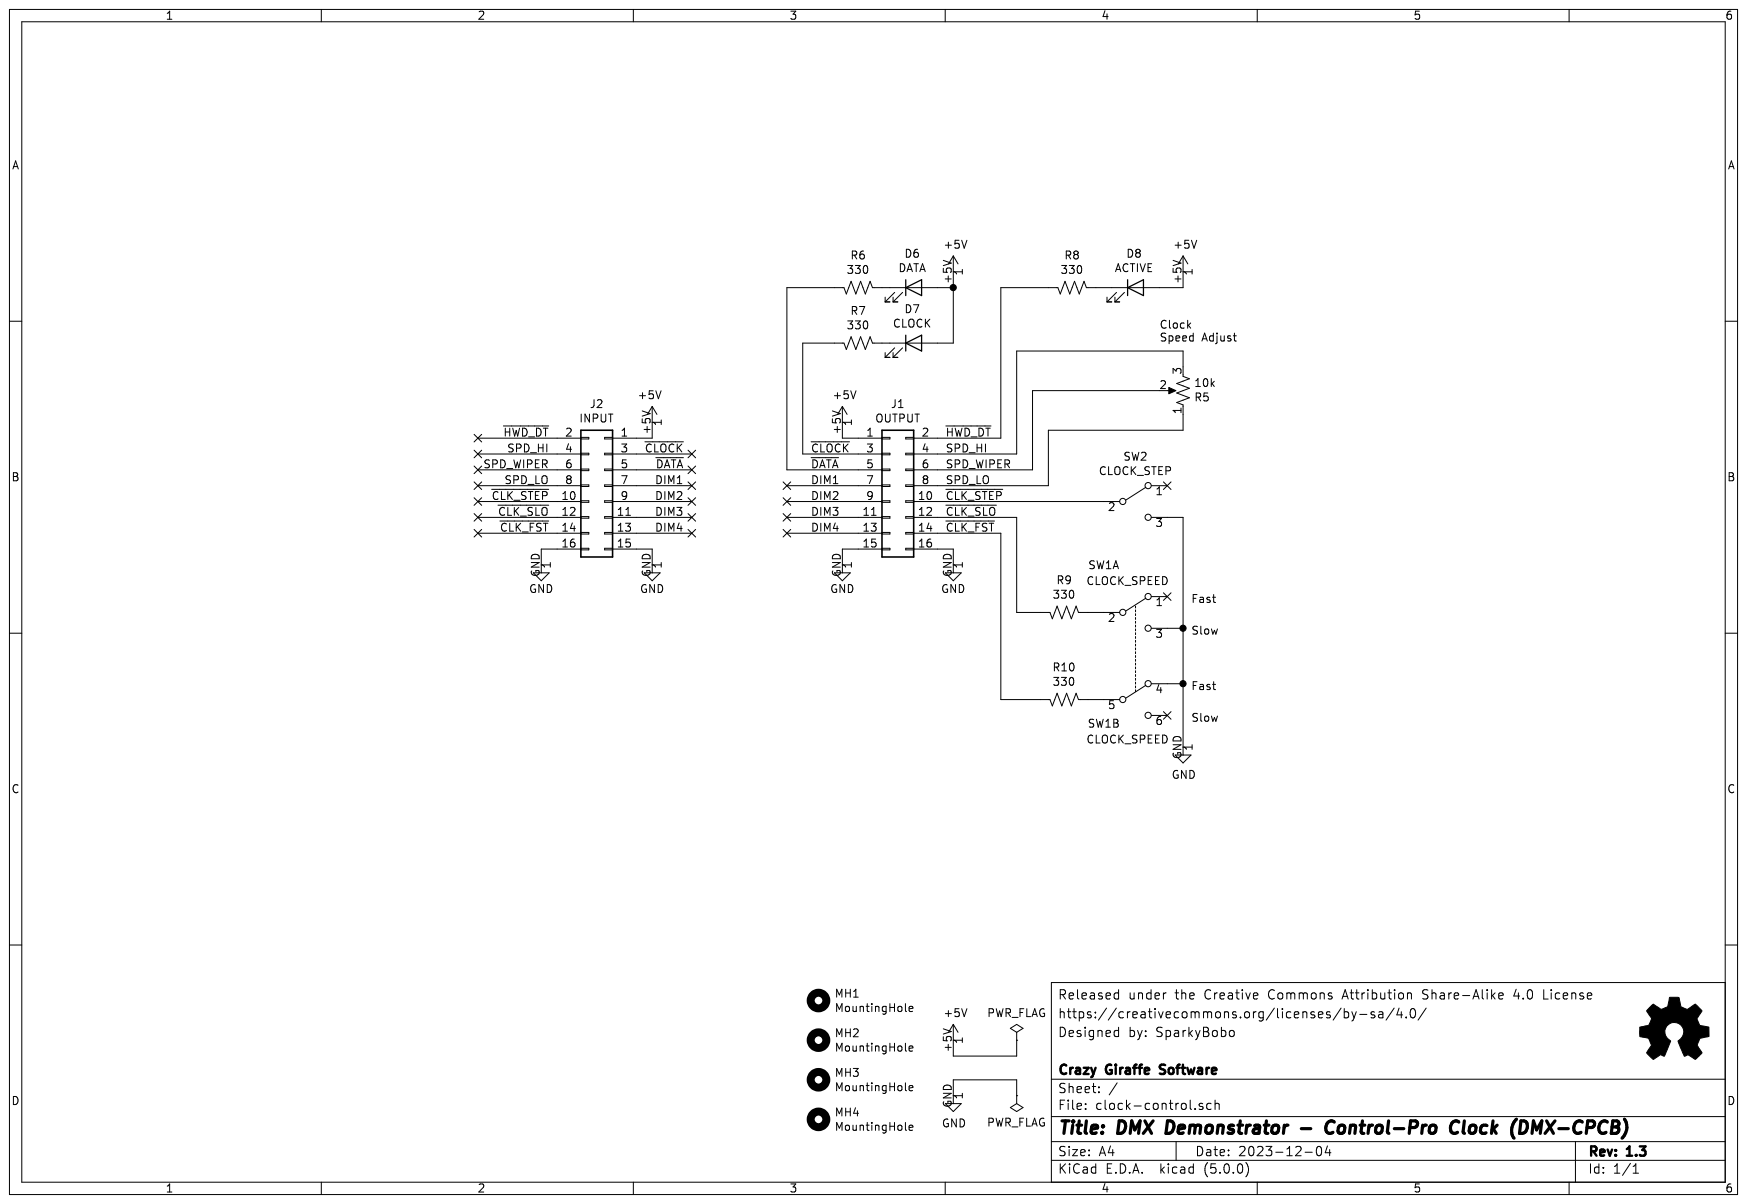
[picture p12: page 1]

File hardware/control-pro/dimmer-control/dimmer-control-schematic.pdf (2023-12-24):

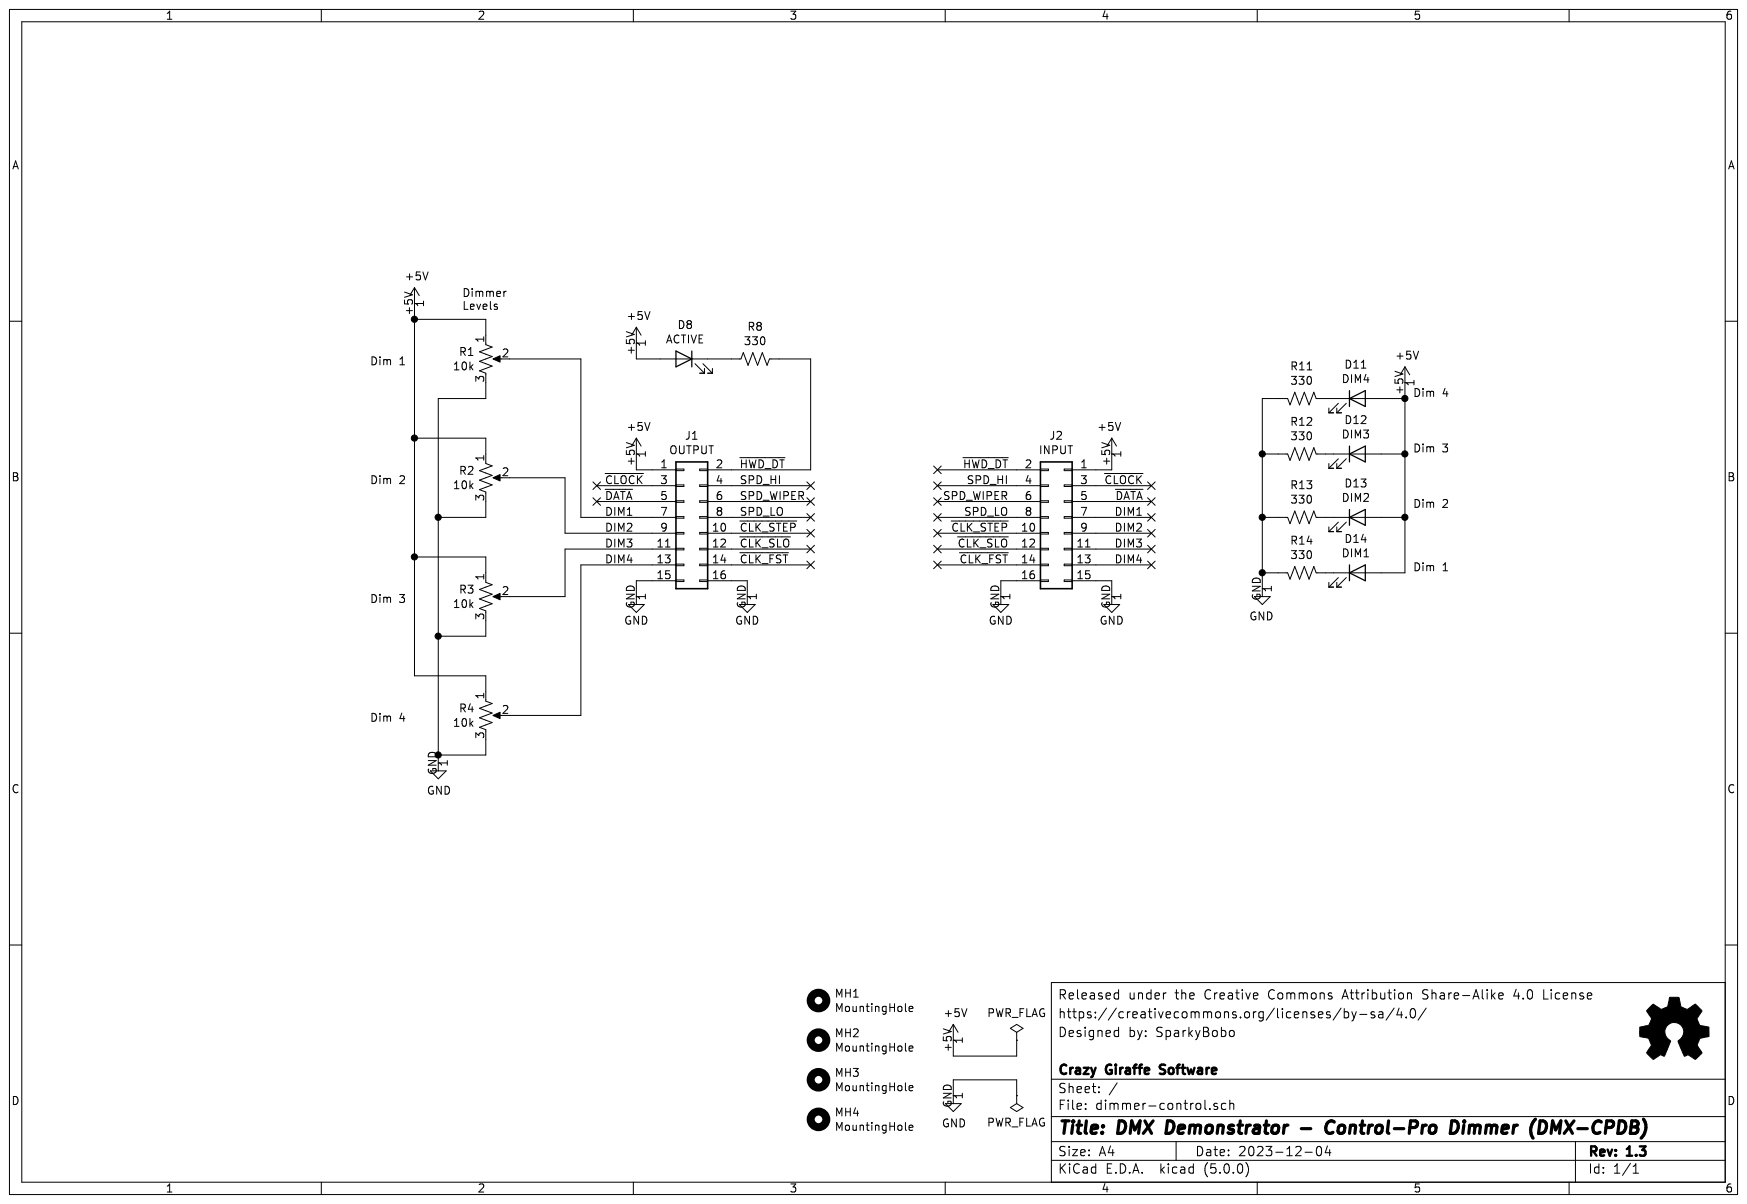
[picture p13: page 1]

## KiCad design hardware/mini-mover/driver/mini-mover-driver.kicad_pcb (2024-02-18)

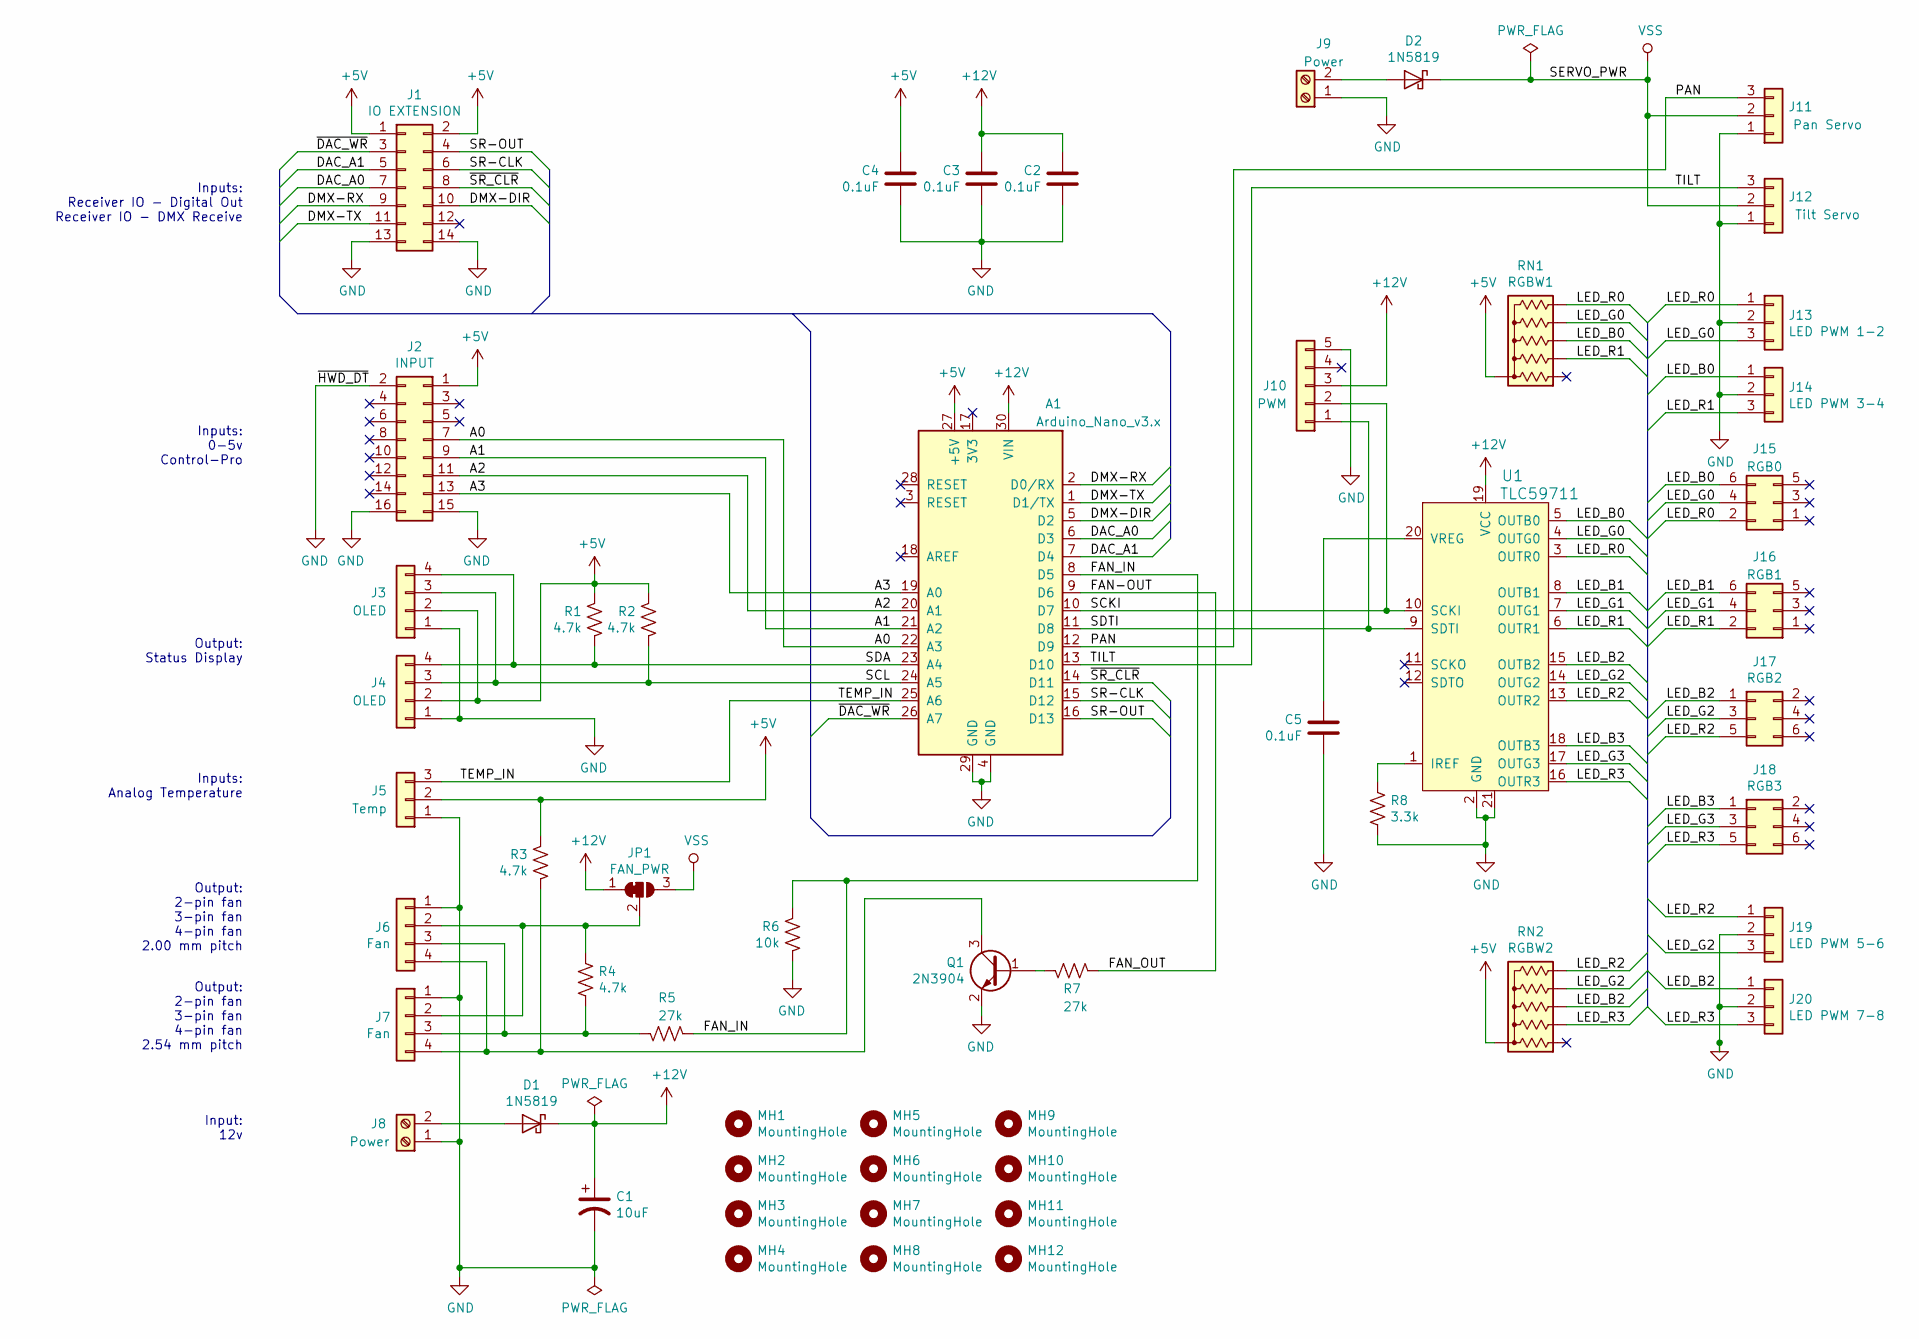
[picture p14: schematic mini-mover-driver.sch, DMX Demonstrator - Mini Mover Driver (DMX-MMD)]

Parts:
A1: Arduino_Nano_v3.x; Arduino_Nano
C1: 10uF; CP_Radial_D5.0mm_P2.50mm; Digi-Key_PN P10425CT-ND
C2, C4: 0.1uF; C_Rect_L4.6mm_W2.0mm_P2.50mm_MKS02_FKP02
C3, C5: 0.1uF; C_1206_3216Metric_Pad1.42x1.75mm_HandSolder
D1, D2: 1N5819; D_DO-41_SOD81_P10.16mm_Horizontal; Digi-Key_PN 1N5819-E3/54GITR-ND
J1: IO EXTENSION; IDC-Header_2x07_P2.54mm_Vertical
J2: INPUT; IDC-Header_2x08_P2.54mm_Vertical
J3, J4: OLED; PinHeader_1x04_P2.54mm_Vertical
J5: Temp; PinHeader_1x03_P2.54mm_Vertical
J6: Fan; PinHeader_1x04_P2.00mm_Vertical
J7: Fan; PinHeader_1x04_P2.54mm_Vertical
J8, J9: Power; PhoenixContact_MC_1,5_2-G-3.81_1x02_P3.81mm_Horizontal; Digi-Key_PN 277-1106-ND
J10: PWM; PinHeader_1x05_P2.54mm_Vertical
J11: Pan Servo; PinHeader_1x03_P2.54mm_Vertical
J12: Tilt Servo; PinHeader_1x03_P2.54mm_Vertical
J13: LED PWM 1-2; PinHeader_1x03_P2.54mm_Vertical
J14: LED PWM 3-4; PinHeader_1x03_P2.54mm_Vertical
J15: RGB0; PinHeader_2x03_P2.54mm_Vertical
J16: RGB1; PinHeader_2x03_P2.54mm_Vertical
J17: RGB2; PinHeader_2x03_P2.54mm_Vertical
J18: RGB3; PinHeader_2x03_P2.54mm_Vertical
J19: LED PWM 5-6; PinHeader_1x03_P2.54mm_Vertical
J20: LED PWM 7-8; PinHeader_1x03_P2.54mm_Vertical
JP1: FAN_PWR; SolderJumper-3_P1.3mm_Bridged12_RoundedPad1.0x1.5mm
MH1, MH2, MH3, MH4, MH5, MH6, MH7, MH8: MountingHole; MountingHole_3.2mm_M3
MH9, MH10, MH11, MH12: MountingHole; MountingHole_2.2mm_M2
Q1: 2N3904; TO-92L_HandSolder
R1, R2, R3, R4: 4.7k; R_Axial_DIN0207_L6.3mm_D2.5mm_P10.16mm_Horizontal
R5, R7: 27k; R_Axial_DIN0207_L6.3mm_D2.5mm_P10.16mm_Horizontal
R6: 10k; R_Axial_DIN0207_L6.3mm_D2.5mm_P10.16mm_Horizontal
R8: 3.3k; R_1206_3216Metric_Pad1.42x1.75mm_HandSolder
RN1: RGBW1; R_Array_SIP6
RN2: RGBW2; R_Array_SIP6
U1: TLC59711; TSSOP-20-1EP_W4.4mm; MPN TLC59711PWPR; Digi-Key_PN 296-36745-1-ND

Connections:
+5V: A1.27 (+5V), C4.1, J1.1, J1.2, J2.1, J2.4, J3.2, J4.2, J5.2, R1.1, R2.1, R3.1, RN1.1 (common), RN2.1 (common)
+12V: A1.30 (VIN), C1.1, C2.1, C3.1, D1.1 (K), J10.3, JP1.1 (A), U1.19 (VCC)
/A0: A1.22 (A3), J2.7
/A1: A1.21 (A2), J2.9
/A2: A1.20 (A1), J2.11
/A3: A1.19 (A0), J2.13
/DAC_A0: A1.6 (D3), J1.7
/DAC_A1: A1.7 (D4), J1.5
/DMX-DIR: A1.5 (D2), J1.10
/DMX-RX: A1.2 (D0/RX), J1.9
/DMX-TX: A1.1 (D1/TX), J1.11
/FAN-OUT: A1.9 (D6), R7.1
/FAN_IN: A1.8 (D5), R5.1, R6.1
/LED_B0: J14.1, J15.6, RN1.4 (R3), U1.5 (OUTB0)
/LED_B1: J16.6, U1.8 (OUTB1)
/LED_B2: J17.1, J20.1, RN2.4 (R3), U1.15 (OUTB2)
/LED_B3: J18.1, U1.18 (OUTB3)
/LED_G0: J13.3, J15.4, RN1.5 (R4), U1.4 (OUTG0)
/LED_G1: J16.4, U1.7 (OUTG1)
/LED_G2: J17.3, J19.3, RN2.5 (R4), U1.14 (OUTG2)
/LED_G3: J18.3, U1.17 (OUTG3)
/LED_R0: J13.1, J15.2, RN1.6 (R5), U1.3 (OUTR0)
/LED_R1: J14.3, J16.2, RN1.3 (R2), U1.6 (OUTR1)
/LED_R2: J17.5, J19.1, RN2.6 (R5), U1.13 (OUTR2)
/LED_R3: J18.5, J20.3, RN2.3 (R2), U1.16 (OUTR3)
/PAN: A1.12 (D9), J11.3
/SCKI: A1.10 (D7), J10.2, U1.10 (SCKI)
/SCL: A1.24 (A5), J3.3, J4.3, R2.2
/SDA: A1.23 (A4), J3.4, J4.4, R1.2
/SDTI: A1.11 (D8), J10.1, U1.9 (SDTI)
/SR-CLK: A1.15 (D12), J1.6
/SR-OUT: A1.16 (D13), J1.4
/TEMP_IN: A1.25 (A6), J5.3
/TILT: A1.13 (D10), J12.3
/~DAC_WR: A1.26 (A7), J1.3
/~SR_CLR: A1.14 (D11), J1.8
GND: A1.4 (GND), A1.29 (GND), C1.2, C2.2, C3.2, C4.2, C5.2, J1.13, J1.14, J2.2, J2.8, J2.15, J2.16, J3.1, J4.1, J5.1, J6.1, J7.1, J8.1, J9.1, J10.5, J11.1, J12.1, J13.2, J14.2, J19.2, J20.2, Q1.2 (E), R6.2, R8.2, U1.2 (GND), U1.21
unnamed: C5.1, U1.20 (VREG)
unnamed: D1.2 (A), J8.2
unnamed: D2.2 (A), J9.2
unnamed: J6.2, J7.2, JP1.2 (C), R4.1
unnamed: J6.3, J7.3, R4.2, R5.2
unnamed: J6.4, J7.4, Q1.3 (C), R3.2
unnamed: Q1.1 (B), R7.2
unnamed: R8.1, U1.1 (IREF)
VSS: D2.1 (K), J11.2, J12.2, JP1.3 (B)

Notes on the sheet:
Inputs: Receiver IO - Digital Out Receiver IO - DMX Receive
Inputs: 0-5v Control-Pro
Inputs: Analog Temperature
Output: 2-pin fan 3-pin fan 4-pin fan 2.00 mm pitch
Output: 2-pin fan 3-pin fan 4-pin fan 2.54 mm pitch
Input: 12v
Output: Status Display

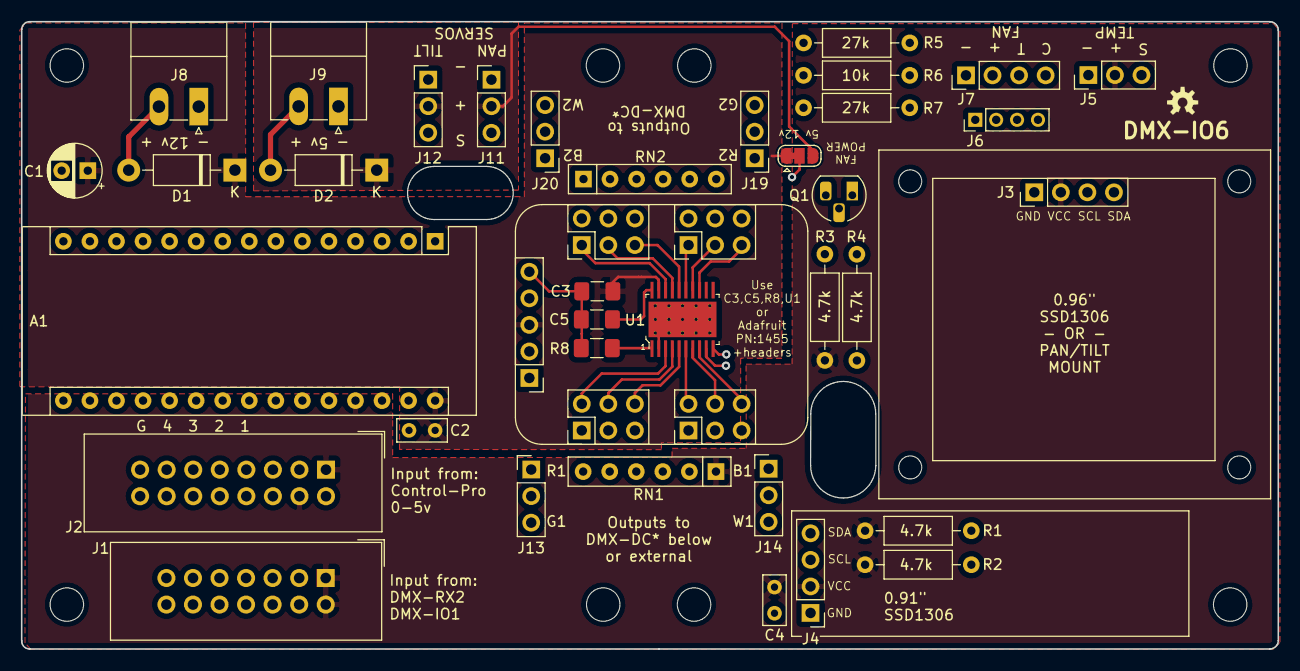
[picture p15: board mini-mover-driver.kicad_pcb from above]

Board: 4 copper layers, 120.2 x 60.0 mm, 53 parts (0 on the bottom side), 46 nets.

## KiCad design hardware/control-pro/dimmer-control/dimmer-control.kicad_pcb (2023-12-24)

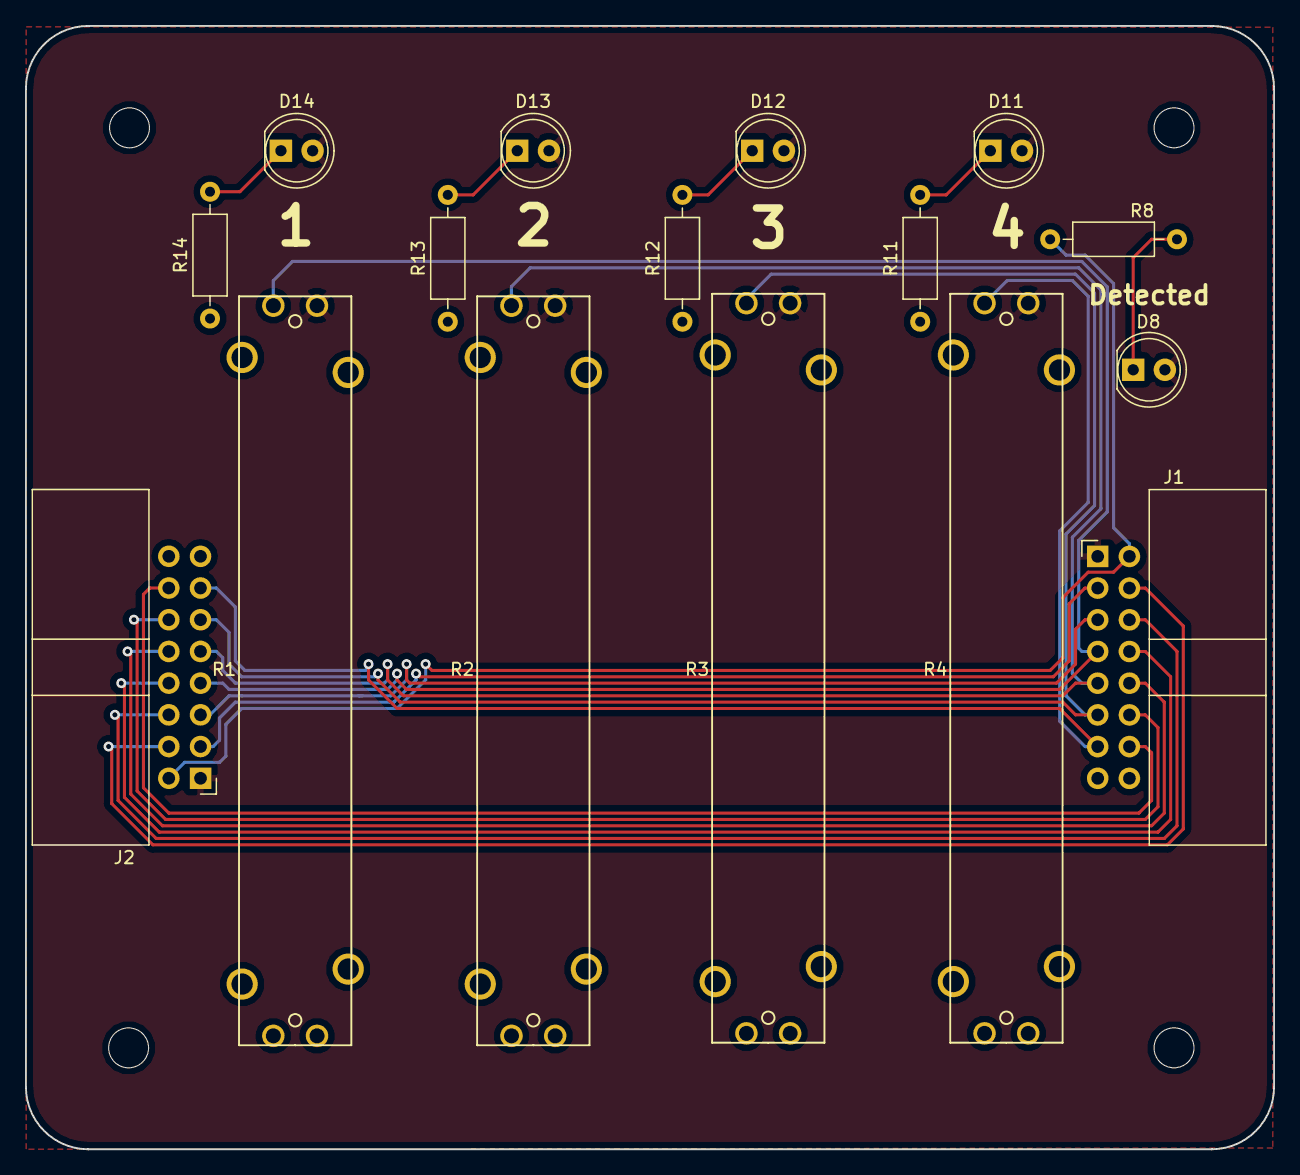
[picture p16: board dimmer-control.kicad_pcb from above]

Board: 2 copper layers, 100.0 x 90.0 mm, 20 parts (0 on the bottom side), 20 nets.

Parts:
D8: LED; LED_D5.0mm
D11: DIM4; LED_D5.0mm
D12: DIM3; LED_D5.0mm
D13: DIM2; LED_D5.0mm
D14: DIM1; LED_D5.0mm
J1: OUTPUT; IDC-Header_2x08_P2.54mm_Horizontal
J2: INPUT; IDC-Header_2x08_P2.54mm_Horizontal
MH1, MH2, MH3, MH4: MountingHole; MountingHole_3.2mm_M3
R1, R2, R3, R4: 10k; BOURNS_PTA4543
R8, R11, R12, R13, R14: 330; R_Axial_DIN0207_L6.3mm_D2.5mm_P10.16mm_Horizontal

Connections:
+5V: D8.2, D11.2, D12.2, D13.2, D14.2, J1.1, J2.1, R1.1, R2.1, R3.1, R4.1
/DIM1: J1.7, J2.7, R1.2
/DIM2: J1.9, J2.9, R2.2
/DIM3: J1.11, J2.11, R3.2
/DIM4: J1.13, J2.13, R4.2
/SPD_HI: J1.4, J2.4
/SPD_LO: J1.8, J2.8
/SPD_WIPER: J1.6, J2.6
/~CLK_FST: J1.14, J2.14
/~CLK_SLO: J1.12, J2.12
/~CLK_STEP: J1.10, J2.10
/~CLOCK: J1.3, J2.3
/~DATA: J1.5, J2.5
/~HWD_DT: J1.2, J2.2, R8.1
GND: J1.15, J1.16, J2.15, J2.16, R1.3, R2.3, R3.3, R4.3, R11.1, R12.1, R13.1, R14.1
unnamed: D8.1, R8.2
unnamed: D11.1, R11.2
unnamed: D12.1, R12.2
unnamed: D13.1, R13.2
unnamed: D14.1, R14.2

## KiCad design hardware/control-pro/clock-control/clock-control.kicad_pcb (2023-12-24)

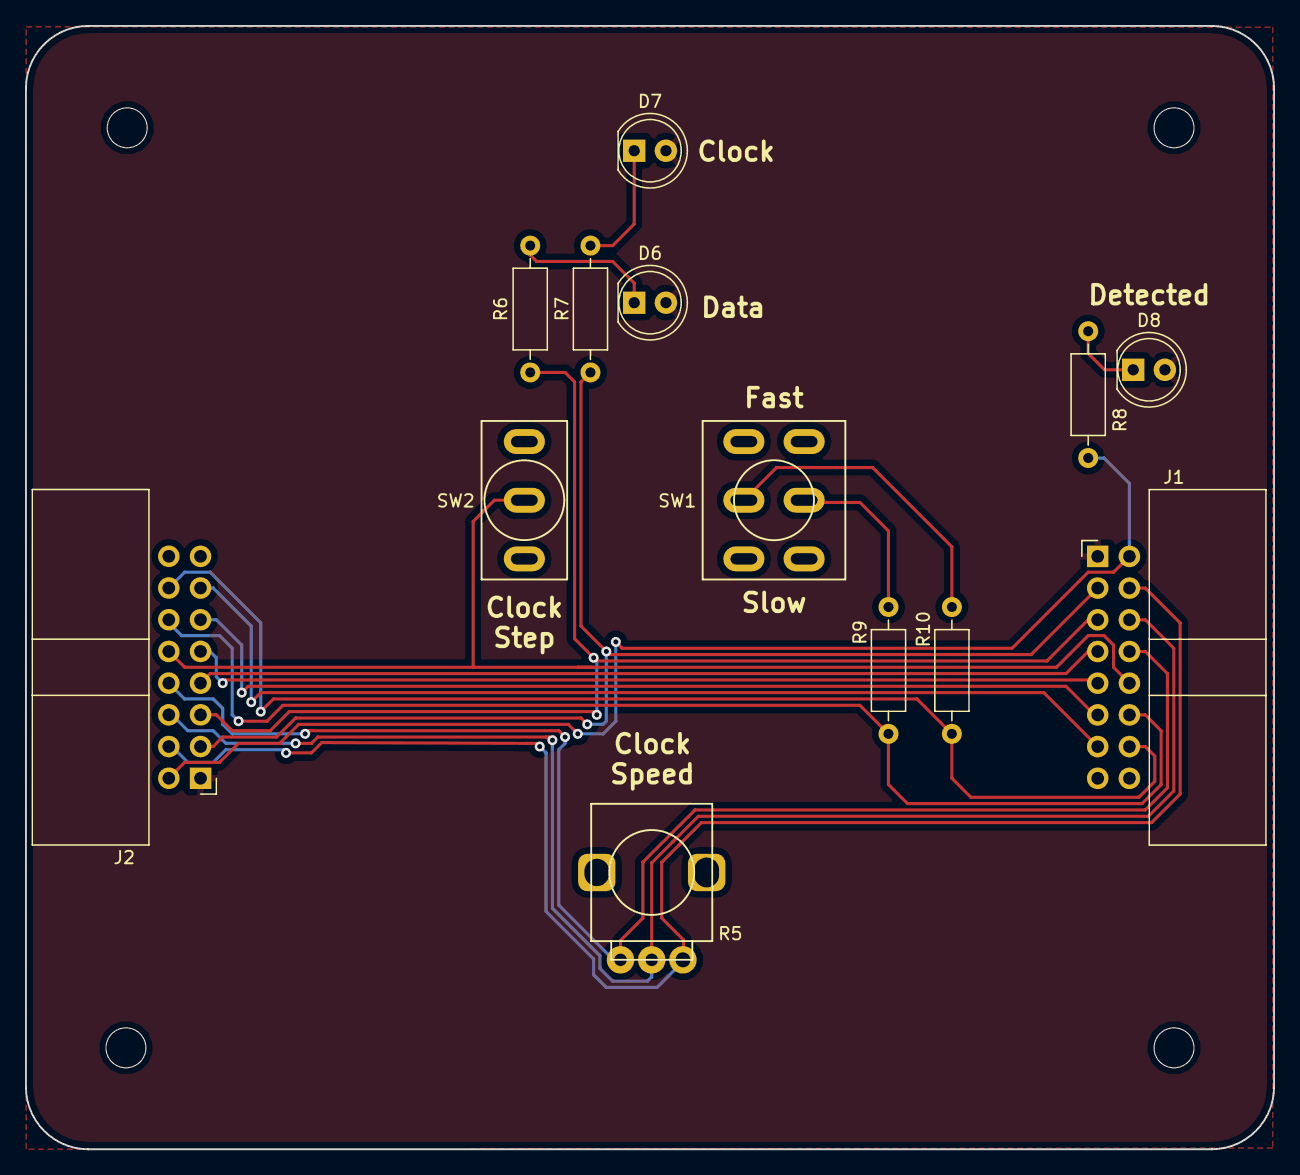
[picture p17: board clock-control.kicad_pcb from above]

Board: 2 copper layers, 100.0 x 90.0 mm, 17 parts (0 on the bottom side), 20 nets.

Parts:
D6: DATA; LED_D5.0mm
D7: CLOCK; LED_D5.0mm
D8: ACTIVE; LED_D5.0mm
J1: OUTPUT; IDC-Header_2x08_P2.54mm_Horizontal
J2: INPUT; IDC-Header_2x08_P2.54mm_Horizontal
MH1, MH2, MH3, MH4: MountingHole; MountingHole_3.2mm_M3
R5: 10k; BOURNS_PTV09A_1
R6, R7, R8, R9, R10: 330; R_Axial_DIN0207_L6.3mm_D2.5mm_P10.16mm_Horizontal
SW1: CLOCK_SPEED; ESWITCH_100_DPDT_M1
SW2: CLOCK_STEP; ESWITCH_100_SPDT_M1

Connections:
+5V: D6.2, D7.2, D8.2, J1.1, J2.1
/DIM1: J1.7, J2.7
/DIM2: J1.9, J2.9
/DIM3: J1.11, J2.11
/DIM4: J1.13, J2.13
/SPD_HI: J1.4, J2.4, R5.3
/SPD_LO: J1.8, J2.8, R5.1
/SPD_WIPER: J1.6, J2.6, R5.2
/~CLK_FST: J1.14, J2.14, R10.1
/~CLK_SLO: J1.12, J2.12, R9.1
/~CLK_STEP: J1.10, J2.10, SW2.2
/~CLOCK: J1.3, J2.3, R7.1
/~DATA: J1.5, J2.5, R6.1
/~HWD_DT: J1.2, J2.2, R8.1
GND: J1.15, J1.16, J2.15, J2.16, SW1.3, SW1.4, SW2.3
unnamed: D6.1, R6.2
unnamed: D7.1, R7.2
unnamed: D8.1, R8.2
unnamed: R9.2, SW1.2
unnamed: R10.2, SW1.5

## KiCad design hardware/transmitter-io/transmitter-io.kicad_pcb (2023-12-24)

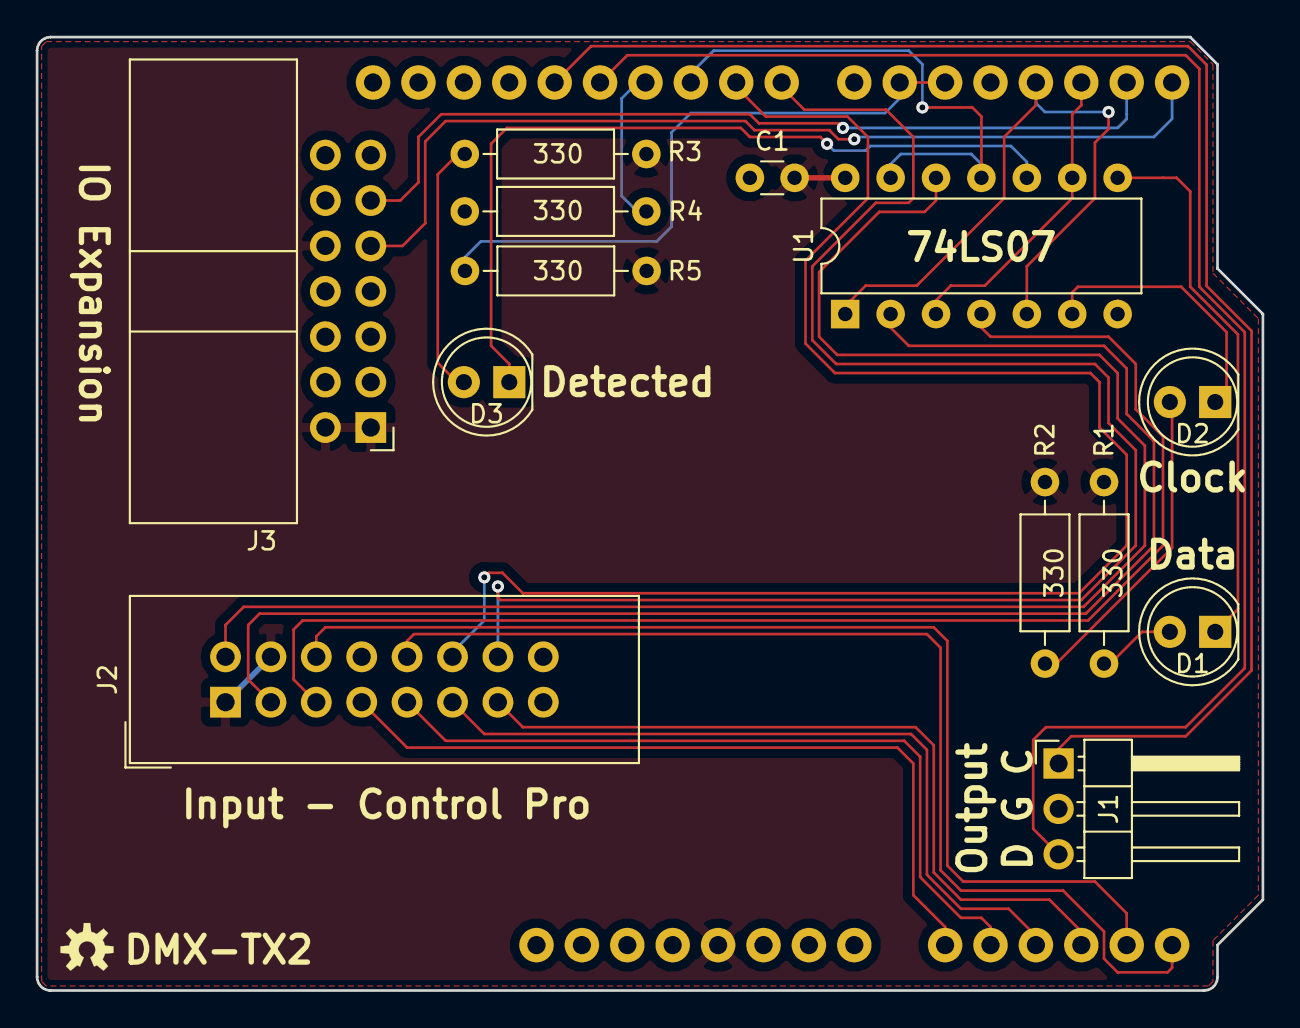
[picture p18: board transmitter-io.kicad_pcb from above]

Board: 2 copper layers, 68.6 x 53.3 mm, 14 parts (0 on the bottom side), 28 nets.

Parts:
A1: Arduino_UNO_R3; ARDUINO_R3_NO_HOLES
C1: 0.1uF; C_Disc_D3.0mm_W1.6mm_P2.50mm
D1: DATA; LED_D5.0mm
D2: CLOCK; LED_D5.0mm
D3: DETECTED; LED_D5.0mm
J1: Output; PinHeader_1x03_P2.54mm_Horizontal
J2: INPUT; IDC-Header_2x08_P2.54mm_Vertical
J3: IO EXTENSION; IDC-Header_2x07_P2.54mm_Horizontal
R1, R2, R3, R4, R5: 330; R_Axial_DIN0207_L6.3mm_D2.5mm_P10.16mm_Horizontal
U1: 74LS07; DIP-14_W7.62mm

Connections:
+5V: A1.5, C1.2, J2.1, J2.4, J3.1, J3.2, J3.10, R1.1, R2.1, R3.1, R5.1, U1.14
/A0: A1.9, J2.7
/A1: A1.10, J2.9
/A2: A1.11, J2.11
/A3: A1.12, J2.13
/A4: A1.13, J2.6
/A5: A1.14, J2.10
/RX: A1.27, J1.3
/RXCLK: A1.28, J1.1
/~CLK_FST: A1.23, J2.14
/~CLK_SLO: A1.24, J2.12
/~CLOCK: J2.3, U1.2
/~CLOCK_OUT: A1.18, U1.1, U1.5
/~DATA: J2.5, U1.4
/~DATA_OUT: A1.17, U1.3, U1.9
/~HWD_DT: J2.2, U1.12
/~HWD_DT_OUT: A1.25, U1.11, U1.13
GND: A1.6, A1.7, A1.29, C1.1, J1.2, J2.8, J2.15, J2.16, J3.13, J3.14, R4.2, U1.7
unnamed: A1.15, J3.9
unnamed: A1.16, J3.11
unnamed: A1.20, A1.21, R5.2
unnamed: A1.26, R4.1
unnamed: D1.1, U1.8
unnamed: D1.2, R1.2
unnamed: D2.1, U1.6
unnamed: D2.2, R2.2
unnamed: D3.1, U1.10
unnamed: D3.2, R3.2

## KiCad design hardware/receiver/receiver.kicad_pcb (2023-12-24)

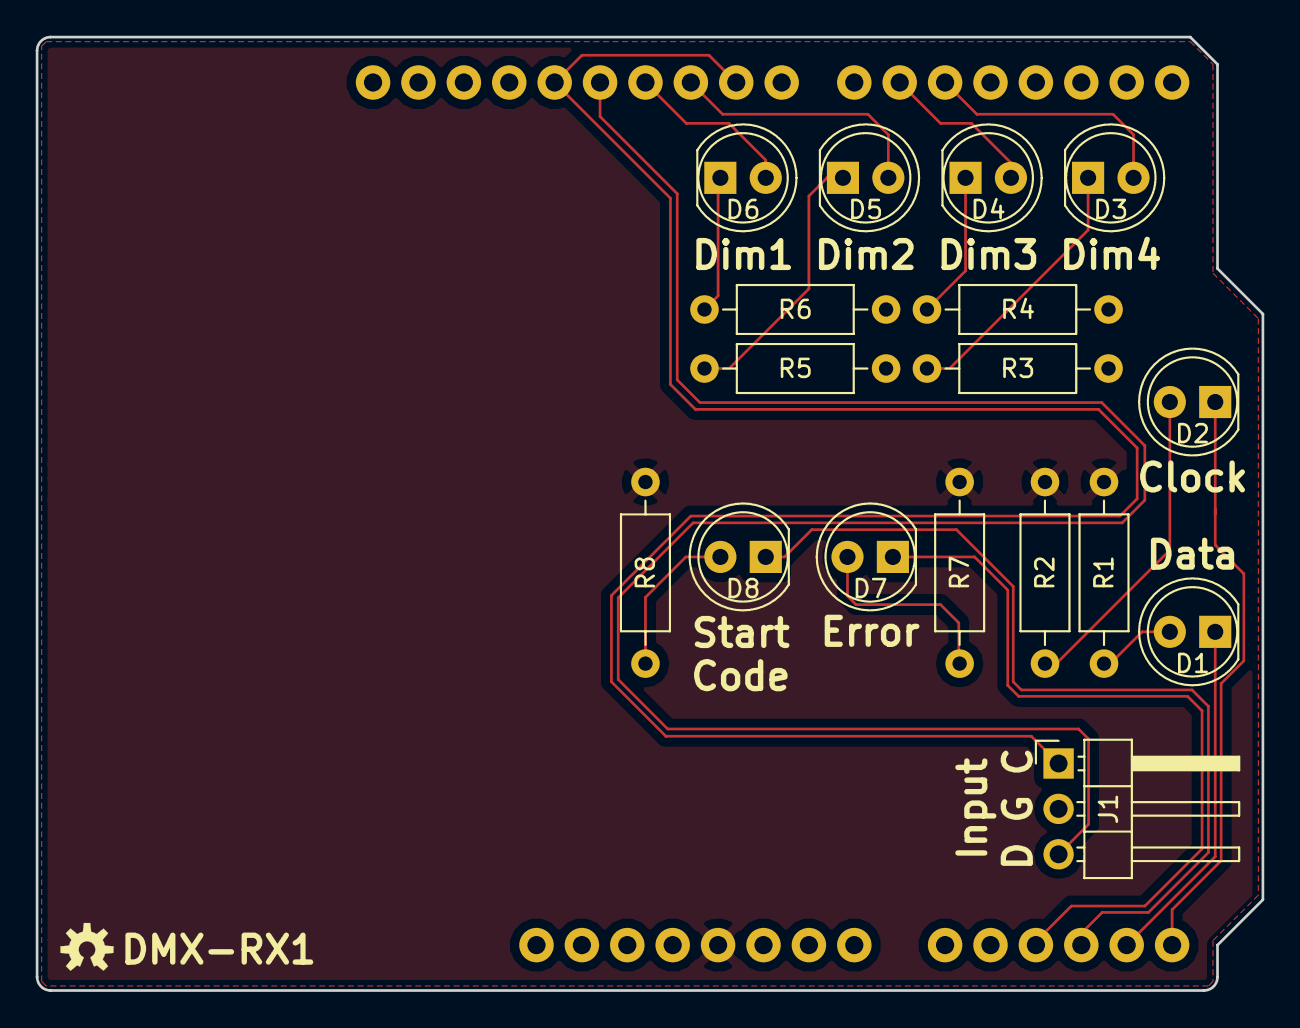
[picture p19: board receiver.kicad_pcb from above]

Board: 2 copper layers, 68.6 x 53.3 mm, 18 parts (0 on the bottom side), 20 nets.

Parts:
A1: Arduino_UNO_R3; ARDUINO_R3_NO_HOLES
D1: DATA; LED_D5.0mm
D2: CLOCK; LED_D5.0mm
D3: DIM3; LED_D5.0mm
D4: DIM2; LED_D5.0mm
D5: DIM1; LED_D5.0mm
D6: DIM0; LED_D5.0mm
D7: ERROR; LED_D5.0mm
D8: START_CODE; LED_D5.0mm
J1: Input; PinHeader_1x03_P2.54mm_Horizontal
R1, R2, R3, R4, R5, R6, R7, R8: 330; R_Axial_DIN0207_L6.3mm_D2.5mm_P10.16mm_Horizontal

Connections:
+5V: A1.5, R1.1, R2.1, R7.1, R8.1
/RX: A1.27, J1.3
/RXCLK: A1.24, A1.28, J1.1
/~CLOCK: A1.14, D2.1
/~DATA: A1.13, D1.1
/~DIM0: A1.26, D6.2
/~DIM1: A1.25, D5.2
/~DIM2: A1.21, D4.2
/~DIM3: A1.20, D3.2
/~ERR: A1.11, D7.1
/~SC: A1.12, D8.1
GND: A1.6, A1.7, A1.29, J1.2, R3.1, R4.1, R5.1, R6.1
unnamed: D1.2, R1.2
unnamed: D2.2, R2.2
unnamed: D3.1, R3.2
unnamed: D4.1, R4.2
unnamed: D5.1, R5.2
unnamed: D6.1, R6.2
unnamed: D7.2, R7.2
unnamed: D8.2, R8.2

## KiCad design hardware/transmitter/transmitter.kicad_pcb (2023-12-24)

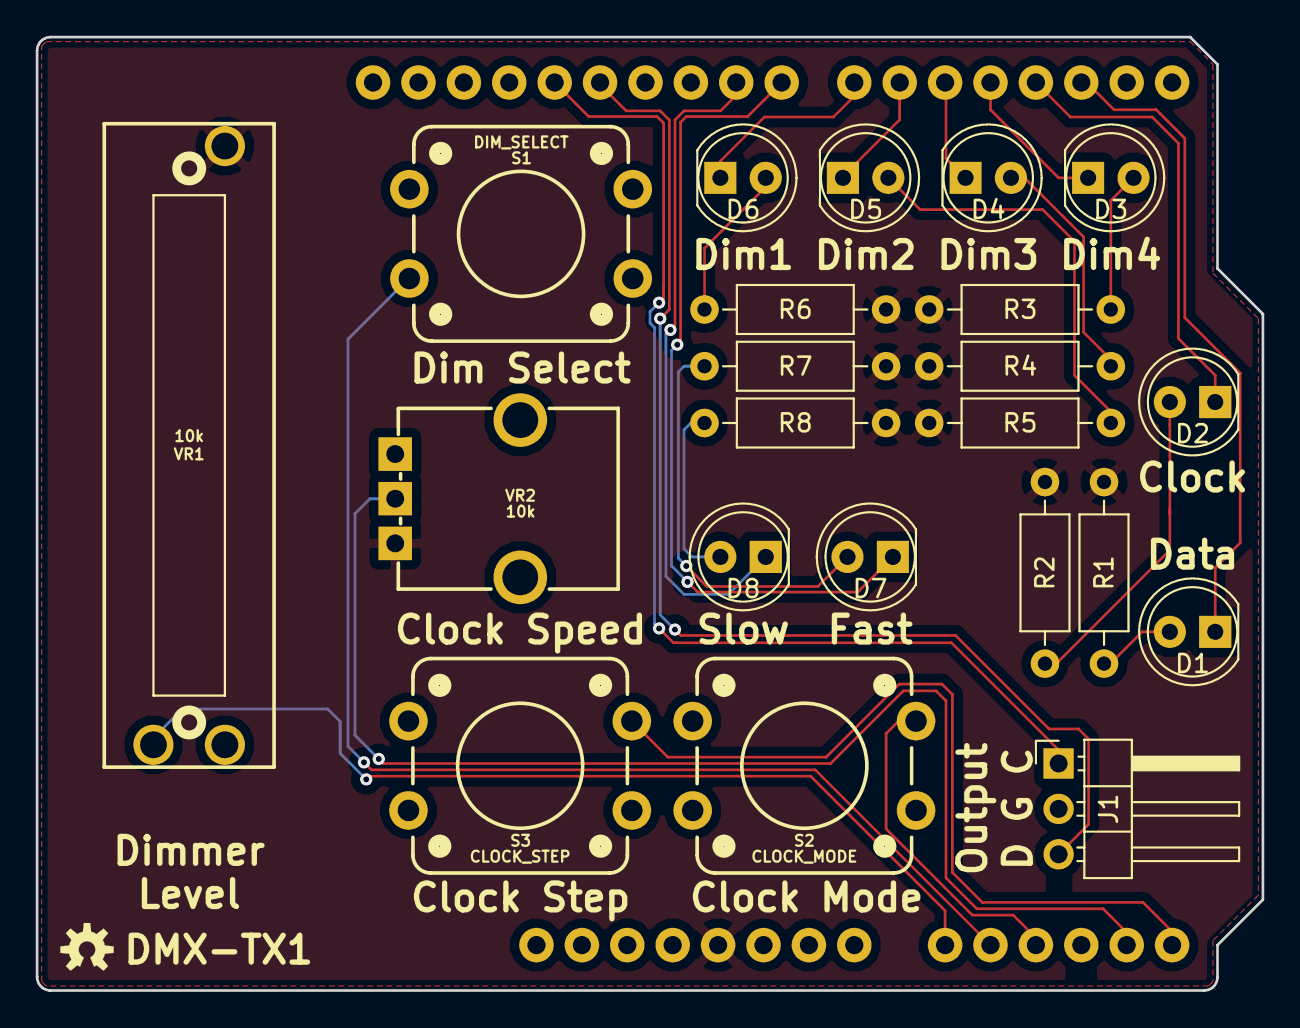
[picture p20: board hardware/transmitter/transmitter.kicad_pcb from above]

Board: 2 copper layers, 68.6 x 53.3 mm, 23 parts (0 on the bottom side), 25 nets.

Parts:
A1: Arduino_UNO_R3; ARDUINO_R3_NO_HOLES
D1: DATA; LED_D5.0mm
D2: CLOCK; LED_D5.0mm
D3: DIM3; LED_D5.0mm
D4: DIM2; LED_D5.0mm
D5: DIM1; LED_D5.0mm
D6: DIM0; LED_D5.0mm
D7: CLK_FST; LED_D5.0mm
D8: CLK_SLO; LED_D5.0mm
J1: Output; PinHeader_1x03_P2.54mm_Horizontal
R1, R2, R3, R4, R5, R6, R7, R8: 330; R_Axial_DIN0207_L6.3mm_D2.5mm_P10.16mm_Horizontal
S1: DIM_SELECT; TACTILE_SWITCH_PTH_12MM
S2: CLOCK_MODE; TACTILE_SWITCH_PTH_12MM
S3: CLOCK_STEP; TACTILE_SWITCH_PTH_12MM
VR1: 10k; SLIDER-SMALL
VR2: 10k; POT-PTH-ALPS

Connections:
+5V: A1.5, R1.1, R2.1, R3.1, R4.1, R5.1, R6.1, R7.1, R8.1, VR1.BOTT, VR2.P$3
/A0: A1.9, VR1.WIPE
/A1: A1.10, S1.3
/A2: A1.11, S2.3
/A4: A1.13, VR2.P$2
/A5: A1.14, S3.3
/RX: A1.27, J1.3
/RXCLK: A1.28, J1.1
/~CLK_FST: A1.23, D7.1
/~CLK_SLO: A1.24, D8.1
/~CLOCK: A1.18, D2.1
/~DATA: A1.17, D1.1
/~DIM0: A1.22, D6.1
/~DIM1: A1.21, D5.1
/~DIM2: A1.20, D4.1
/~DIM3: A1.19, D3.1
GND: A1.6, A1.7, A1.29, J1.2, S1.1, S2.1, S3.1, VR1.TOP, VR2.P$1
unnamed: D1.2, R1.2
unnamed: D2.2, R2.2
unnamed: D3.2, R3.2
unnamed: D4.2, R4.2
unnamed: D5.2, R5.2
unnamed: D6.2, R6.2
unnamed: D7.2, R7.2
unnamed: D8.2, R8.2

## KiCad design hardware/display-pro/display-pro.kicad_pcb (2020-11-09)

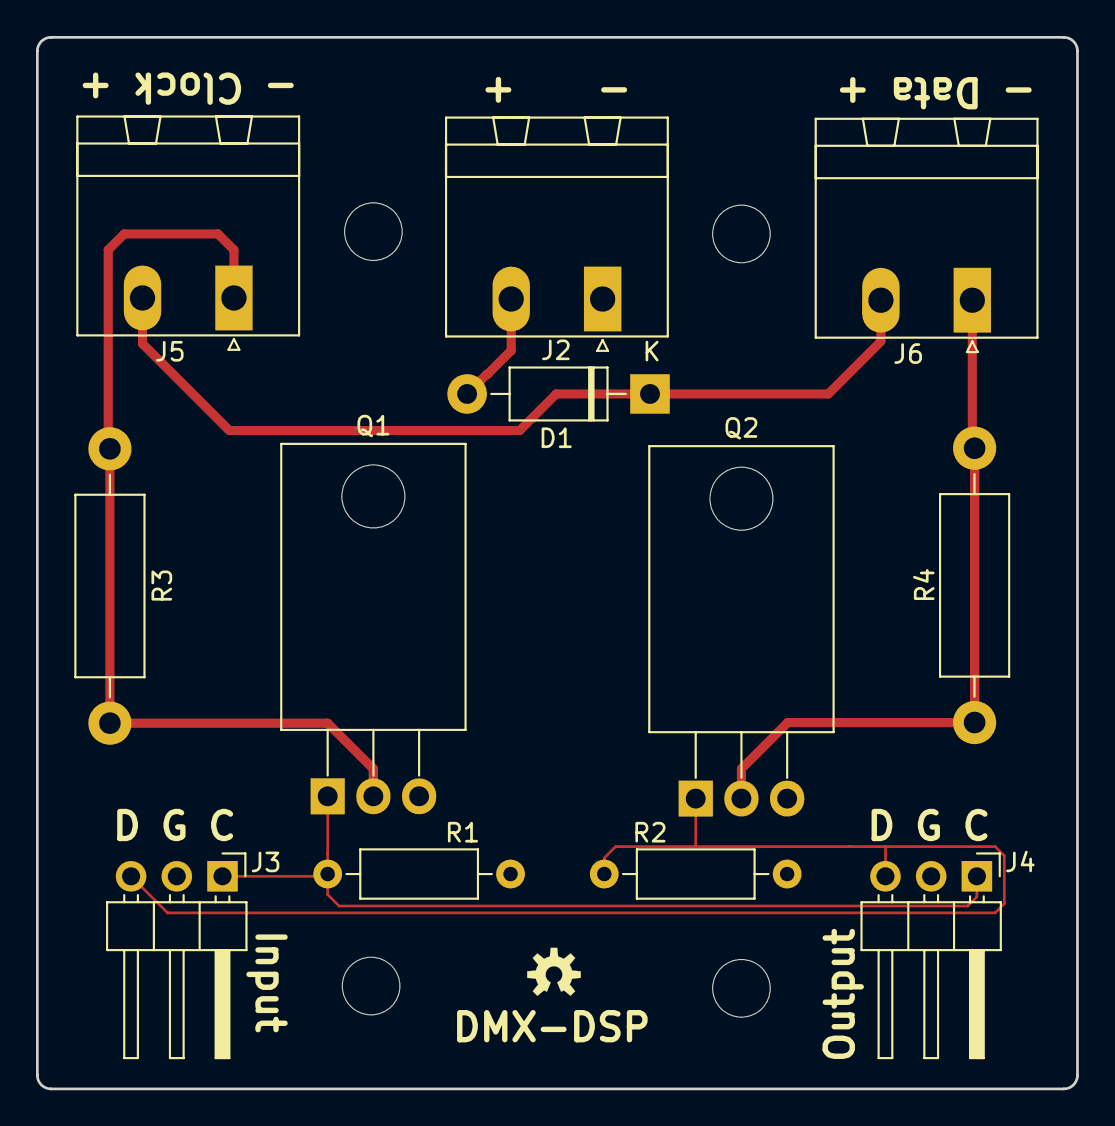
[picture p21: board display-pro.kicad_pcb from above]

Board: 2 copper layers, 57.8 x 58.4 mm, 16 parts (0 on the bottom side), 7 nets.

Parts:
D1: 1N5819; D_DO-41_SOD81_P10.16mm_Horizontal
J2: POWER; PhoenixContact_MSTBA_2,5_2-G-5,08_1x02_P5.08mm_Horizontal
J3: Input; PinHeader_1x03_P2.54mm_Horizontal
J4: Output; PinHeader_1x03_P2.54mm_Horizontal
J5: Clock; PhoenixContact_MSTBA_2,5_2-G-5,08_1x02_P5.08mm_Horizontal
J6: Data; PhoenixContact_MSTBA_2,5_2-G-5,08_1x02_P5.08mm_Horizontal
MH1, MH2, MH3, MH4: MountingHole; MountingHole_3.2mm_M3
Q1, Q2: FQP30N06L; TO-220-3_Horizontal_TabDown
R1, R2: 10k; R_Axial_DIN0207_L6.3mm_D2.5mm_P10.16mm_Horizontal
R3, R4: R?; R_Axial_DIN0411_L9.9mm_D3.6mm_P15.24mm_Horizontal

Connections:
+VDC: D1.1, J5.2, J6.2
/CLOCK: J3.1, J4.1, Q1.1, R1.2
/DATA: J3.3, J4.3, Q2.1, R2.2
GND: J2.1, J3.2, J4.2, Q1.3, Q2.3, R1.1, R2.1
unnamed: D1.2, J2.2
unnamed: J5.1, Q1.2, R3.1, R3.2
unnamed: J6.1, Q2.2, R4.1, R4.2

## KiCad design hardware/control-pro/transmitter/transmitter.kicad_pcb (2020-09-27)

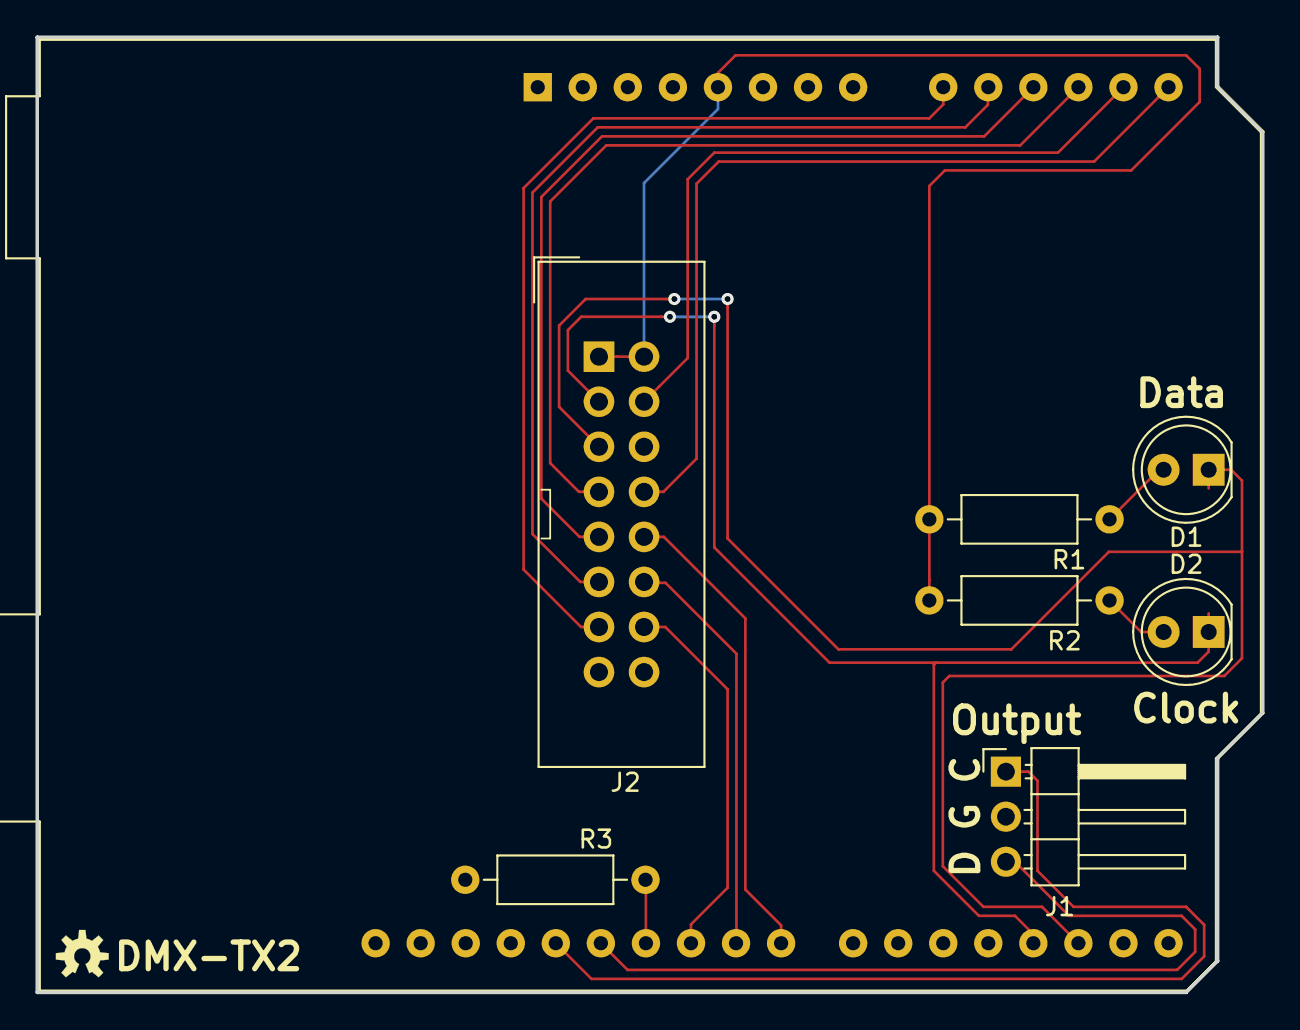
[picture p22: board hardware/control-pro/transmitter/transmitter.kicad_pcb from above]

Board: 2 copper layers, 69.1 x 53.8 mm, 8 parts (0 on the bottom side), 18 nets.

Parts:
A1: Arduino_UNO_R3
D1: DATA; LED_D5.0mm
D2: CLOCK; LED_D5.0mm
J1: Output; PinHeader_1x03_P2.54mm_Horizontal
J2: INPUT; IDC-Header_2x08_P2.54mm_Vertical
R1, R2, R3: 330; R_Axial_DIN0207_L6.3mm_D2.5mm_P10.16mm_Horizontal

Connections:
+5V: A1.5, J2.1, J2.2, R1.1, R2.1
/A0: A1.9, J2.13
/A1: A1.10, J2.11
/A2: A1.11, J2.9
/A3: A1.12, J2.7
/A4: A1.13, J2.4
/A5: A1.14, J2.8
/RX: A1.27, J1.3
/RXCLK: A1.28, J1.1
/~CLK_FST: A1.24, J2.12
/~CLK_SLO: A1.23, J2.10
/~CLOCK: A1.18, D2.1, J2.3
/~DATA: A1.17, D1.1, J2.5
/~HWD_DT: A1.25, J2.14
GND: A1.6, A1.7, A1.29, J1.2, J2.6, J2.15, J2.16, R3.2
unnamed: A1.26, R3.1
unnamed: D1.2, R1.2
unnamed: D2.2, R2.2

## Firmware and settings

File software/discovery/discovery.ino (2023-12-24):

/**
 * DMX Demonstrator Discovery
 * Copyright (C) 2020 Crazy Giraffe Software
 * https://github.com/crazy-giraffe-software/dmxdemonstrator/tree/master/software/discovery
 *
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
 * You should have received a copy of the GNU General Public License
 * along with this program.  If not, see <http://www.gnu.org/licenses/>.
 */

 /**
 * About DMX Demonstrator Discovery
 *
 * This software supports the Arduio-based DMX Demonstrator boards
 * to determine the configuration and status. This is used by the
 * desktop program to determine what configuration is left to perform
 * before flashing the final software.
 */
#define _VERSION_ "1.1"

// Local copy of JC_Button: https://github.com/JChristensen/JC_Button
#include "JC_Button.h"

/**
 * Pin definitions.
 */
int dimmerLevelInputPin = A0;     // The single dimmer level control for the 'lite' transmitter control.
int dimmerLevel1InputPin = A0;    // The dimmer 1 level control for the 'pro' transmitter control.
int dimmerLevel2InputPin = A1;    // The dimmer 2 level control for the 'pro' transmitter control.
int dimmerSelectButtonPin = A1;   // The dimmer select button for the 'lite' transmitter control.
int dimmerLevel3InputPin = A2;    // The dimmer 3 level control for the 'pro' transmitter control.
int clockModeButtonPin = A2;      // The clock mode button for the 'lite' transmitter control.
int errorLedPin = A2;             // The error led output for the receiver.
int dimmerLevel4InputPin = A3;    // The dimmer 4 level control for the 'pro' transmitter control.
int startCodeLedPin = A3;         // The start code led output for the receiver.
int clockSpeedInputPin = A4;      // The clock speed control for both the 'lite' and 'pro' transmitter control.
int dataLedRXPin = A4;            // The data led output for the receiver.
int clockStepButtonPin = A5;      // The clock step button for the 'lite' transmitter control.
int clockLedRXPin = A5;           // The clock led output for the receiver.
int dataLedTXPin = 2;             // The data led output for both the 'lite' and 'pro' transmitter control.
int clockLedTXPin = 3;            // The clock led output for both the 'lite' and 'pro' transmitter control.
int dimmerSelect4LedPin = 4;      // The dimmer select 4 led output for the 'lite' transmitter control.
int dimmerSelect3LedPin = 5;      // The dimmer select 3 led output for the 'lite' transmitter control.
int dimmerLevelOut4LedPin = 5;    // The dimmer output 4 led for the receiver.
int dimmerSelect2LedPin = 6;      // The dimmer select 2 led output for the 'lite' transmitter control.
int dimmerLevelOut3LedPin = 6;    // The dimmer output 3 led for the receiver.
int dimmerSelect1LedPin = 7;      // The dimmer select 1 led output for the 'lite' transmitter control.
int clockFastPin = 8;             // The clock speed fast out for the 'lite' control, in for the "pro" transmitter control.
int clockSlowPin = 9;             // The clock speed slow out for the 'lite' control, in for the "pro" transmitter control.
int dimmerLevelOut2LedPin = 10;   // The dimmer output 2 led for the receiver.
int hardwareDetectOutputPin = 10; // Output to indicate which transmitter board is connected, LOW for DMX-TX2.
int dimmerLevelOut1LedPin = 11;   // The dimmer output 1 led for the receiver.
int hardwareDetectInputPin = 11;  // Input to determine which transmitter board is connected, LOW for DMX-TX2.
int dataInPin = 12;               // The data input from the transmitter.
int dataOutPin = 12;              // The data output to the receiver.
int clockInPin = 13;              // The clock input from the transmitter.
int clockOutPin = 13;             // The clock output to the receiver.

/**
 * Switches
 */
Button dimmerSelectButton = Button(dimmerSelectButtonPin);
Button clockStepButton = Button(clockStepButtonPin);
Button clockModeButton = Button(clockModeButtonPin);
Button clockSlowButton = Button(clockSlowPin);
Button clockFastButton = Button(clockFastPin);

/**
 *  Discovery data.
 */
int detectedBoard = 0; // Determine which board is running.
const int NoBoardDetected = 0;
const int RX1Detected = 1;
const int TX1Detected = 2;
const int TX2Detected = 3;
const int TX2AndControlProDetected = 4;

const char NoBoardMessage[] PROGMEM = "No DMX Demonstrator boards detected.\r\n";
const char rx1Message[] PROGMEM = "DMX-RX1 is detected.\r\n";
const char tx1Message[] PROGMEM = "DMX-TX1 is detected.\r\n";
const char tx2Message[] PROGMEM = "DMX-TX2 is detected.\r\n";
const char controlProMessage[] PROGMEM = "DMX-CP1 is detected.\r\n";

/**
 *  Message for test loop.
 */
volatile int testCounter = -1;
int dimmerValue = 0;
int dimmerValueChange = 0;
int previousClockValue;
int previousDimmerValue;
int previousDimmer2Value;
int previousDimmer3Value;
int previousDimmer4Value;
int analogValueThreshold = 2;

const char testCounterFormat[] PROGMEM = "Dimmer %d LED selected.\r\n";
const char dimmerLEDFormat[] PROGMEM = "Dimmer %d LED selected.\r\n";
const char clockLEDMessage[] PROGMEM = "Clock LED selected.\r\n";
const char dataLEDMessage[] PROGMEM = "Data LED selected.\r\n";
const char fastLEDMessage[] PROGMEM = "Fast LED selected.\r\n";
const char slowLEDMessage[] PROGMEM = "Slow LED selected.\r\n";
const char errorLEDMessage[] PROGMEM = "Error LED selected.\r\n";
const char startCodeLEDMessage[] PROGMEM = "Start Code LED selected.\r\n";
const char clockInMessage[] PROGMEM = "Clock input detected.\r\n";
const char dataInMessage[] PROGMEM = "Data input detected.\r\n";
const char dimmerSelectMessage[] PROGMEM = "Dimmer select input detected.\r\n";
const char clockStepMessage[] PROGMEM = "Clock step input detected.\r\n";
const char clockModeMessage[] PROGMEM = "Clock mode input detected.\r\n";
const char clockSlowInMessage[] PROGMEM = "Clock speed slow input detected.\r\n";
const char clockFastInMessage[] PROGMEM = "Clock speed fast input detected.\r\n";
const char clockSpeedInFormat[] PROGMEM = "Clock variable speed input detected, %d.\r\n";
const char dimmerValueInFormat[] PROGMEM = "Dimmer level input detected, %d.\r\n";
const char dimmer1ValueInFormat[] PROGMEM = "Dimmer 1 level input detected, %d.\r\n";
const char dimmer2ValueInFormat[] PROGMEM = "Dimmer 2 level input detected, %d.\r\n";
const char dimmer3ValueInFormat[] PROGMEM = "Dimmer 3 level input detected, %d.\r\n";
const char dimmer4ValueInFormat[] PROGMEM = "Dimmer 4 level input detected, %d.\r\n";

/**
 * Serial data data.
 */
const long baudRate = 250000;
char serialPortFormat[100];
char serialPortArgument[100];
char serialPortMessage[255];

/**
   The serial responses and help menu.
*/
const char newlineMessage[] PROGMEM = "\r\n";
const char startUpMessage[] PROGMEM = "DMX Demonstrator Discovery starting up...\r\n";
const char readyMessage[] PROGMEM = "DMX Demonstrator Discovery ready!\r\n";
const char versionFormat[] PROGMEM = "DMX Demonstrator Discovery Version %s\r\n";

const char detectBoardStartMessage[] PROGMEM = "Detecting DMX demonstrator board...\r\n";
const char testStartMessage[] PROGMEM = "Starting test...\r\n";
const char testStopMessage[] PROGMEM = "Stopping test...\r\n";

const char helpTitle[] PROGMEM = "Help:\r\n";
const char helpOperationTitle[] PROGMEM = "Operation:\r\n";
const char helpDetectBoard[] PROGMEM = "  d: Detect connected board\r\n";
const char helpStartTest[] PROGMEM = "  t: Test connected board\r\n";
const char helpStoptest[] PROGMEM = "  s: Stop test\r\n";
const char helpInfoTitle[] PROGMEM = "Info:\r\n";
const char helpInfo[] PROGMEM = "  i: Display info\r\n";
const char helpVersion[] PROGMEM = "  v: Display version\r\n";

/**
 * Setup
 * Put your setup code here, to run once.
 */
void setup() {

  // Disable all interrupts.
  noInterrupts();

  // Opens serial port.
  Serial.begin(baudRate);

  // Display startup message.
  SendProgmemMessage(startUpMessage);
  SendProgmemStringFormat(versionFormat, _VERSION_);

  // Configure IO.
  pinMode(10, INPUT);
  pinMode(11, INPUT);

  // Complete startup message.
  SendProgmemMessage(readyMessage);

  // Enable all interrupts.
  interrupts();

  // Scan the board and start tests.
  DetectConnectedBoard();
  InitializeTestTimer();
}

/**
 * Loop
 * Put your main code here, to run repeatedly.
 */
void loop() {

  // Check serial port.
  if (Serial.available() > 0) {
    char incomingByte = Serial.read();
    HandleReceivedChar(incomingByte);
  }
}

/**
 * Timer 1 Interrupt.
 * This code runs once a second.
 */
ISR(TIMER1_COMPA_vect) {
  TestReceiverBoard();
  TestTransmitterTX1Board();
  TestTransmitterTX2Board();
}

/**
 * Initialize test timer.
 * This timer runs once a second and invokes ISR(TIMER1_COMPA_vect).
 */
void InitializeTestTimer() {

  // initialize timer1
  TCCR1A = 0;                   // Reset Timer 1 control register A.
  TCCR1B = 0;                   // Reset Timer 1 control register B.
  TCCR1C = 0;                   // Reset Timer 1 control register C.
  TCNT1  = 0;                   // Reset timer 1 counter value.

  TCCR1B |= (1 << WGM12);       // CTC mode: count to OCR1A.
  TCCR1B |= (1 << CS12);        // Clock 256 prescaler.

  OCR1A = 62500;                // 62500 = 1Hz.
  TIMSK1 |= (1 << OCIE1A);      // Enable timer 1 compare interrupt.
}

/**
 * Determine if a board is connected.
 */
void DetectConnectedBoard() {

  // On the DMX-RX1, pins D5 and D6 are pulled low via LEDs + 330 ohms.
  // On the DMX-TX1, pins D5 and D6 are pulled high via LEDs + 330 ohms.
  // On the DMX-TX2, pins D5 and D6 are not connected.
  // With no board connected, these usually read LOW.
  pinMode(5, INPUT);
  pinMode(6, INPUT);
  int d5State = digitalRead(5);
  int d6State = digitalRead(6);
  int isRX1OrNoBoard = d5State == LOW && d6State == LOW;

  // If it might be the RX1, probe other pins to confirm.
  int isRX1 = isRX1OrNoBoard;
  int isTX1 = !isRX1OrNoBoard;
  int isTX2 = !isRX1OrNoBoard;
  int isControlPro = !isRX1OrNoBoard;
  if (isRX1OrNoBoard) {

    // On the DMX-RX1, pin D10 is pulled low via LED + 330 ohms.
    pinMode(10, INPUT);
    isRX1 &= digitalRead(10) == LOW;

    // On the DMX-RX1, pin D11 is pulled low via LED + 330 ohms.
    pinMode(11, INPUT);
    isRX1 &= digitalRead(11) == LOW;

    // On the DMX-RX1, pin A2 is pulled high via LED + 330 ohms.
    pinMode(A2, INPUT);
    isRX1 &= digitalRead(A2) == HIGH;

    // On the DMX-RX1, pin A3 is pulled high via LED + 330 ohms.
    pinMode(A3, INPUT);
    isRX1 &= digitalRead(A3) == HIGH;

    // On the DMX-RX1, pin A5 is pulled high via LED + 330 ohms.
    pinMode(A4, INPUT);
    isRX1 &= digitalRead(A4) == HIGH;

    // On the DMX-RX1, pin A5 is pulled high via LED + 330 ohms.
    pinMode(A5, INPUT);
    isRX1 &= digitalRead(A5) == HIGH;

  // It might be either TX1 or TX2, probe other pins to confirm.
  } else {

    // On the DMX-TX1, pin D11 is left floating.
    // On the DMX-TX2, pin D11 is pulled low via 330 ohms.
    pinMode(11, INPUT_PULLUP);
    int d11State = digitalRead(11);
    isTX1 &= d11State == HIGH;
    isTX2 &= d11State == LOW;

    // On the DMX-TX1, pin D8 is pulled high via LED + 330 ohms.
    // On the DMX-TX2, pin D8 may be pulled low via the clock mode switch.
    pinMode(8, INPUT_PULLUP);
    isTX1 &= digitalRead(8) == HIGH;
    isControlPro |= digitalRead(8) == LOW;

    // On the DMX-TX1, pin D9 is pulled high via LED + 330 ohms.
    // On the DMX-TX2, pin D9 may be pulled low via the clock mode switch.
    pinMode(9, INPUT_PULLUP);
    isTX1 &= digitalRead(9) == HIGH;
    isControlPro |= digitalRead(9) == LOW;
  }

  // Print discovery.
  if (isRX1) {
    SendProgmemMessage(rx1Message);
    detectedBoard = RX1Detected;
  } else if (isTX1) {
    SendProgmemMessage(tx1Message);
    detectedBoard = TX1Detected;
  } else if (isTX2) {
    SendProgmemMessage(tx2Message);
    if (isControlPro) {
      SendProgmemMessage(controlProMessage);
      detectedBoard = TX2AndControlProDetected;
    } else {
        detectedBoard = TX2Detected;
    }
  } else {
    SendProgmemMessage(NoBoardMessage);
    detectedBoard = NoBoardDetected;
  }
}

/**
 * Run the test sequence for the DMX-RX1.
 */
void TestReceiverBoard() {

  // Skip is not DMX-RX1 or not running a test loop.
  if (testCounter < 0 || detectedBoard != RX1Detected) {
    return;
  }

  // Configure IO.
  if (testCounter == 0) {
    pinMode(errorLedPin, OUTPUT);
    pinMode(startCodeLedPin, OUTPUT);
    pinMode(dataLedRXPin, OUTPUT);
    pinMode(clockLedRXPin, OUTPUT);

    pinMode(dimmerLevelOut1LedPin, OUTPUT);
    pinMode(dimmerLevelOut2LedPin, OUTPUT);
    pinMode(dimmerLevelOut3LedPin, OUTPUT);
    pinMode(dimmerLevelOut4LedPin, OUTPUT);

    pinMode(dataInPin, INPUT_PULLUP);
    pinMode(clockInPin, INPUT_PULLUP);
  }

   // Turn on LEDs.
  digitalWrite(dimmerLevelOut1LedPin, LOW);
  digitalWrite(dimmerLevelOut2LedPin, LOW);
  digitalWrite(dimmerLevelOut3LedPin, LOW);
  digitalWrite(dimmerLevelOut4LedPin, LOW);
  digitalWrite(clockLedRXPin, HIGH);
  digitalWrite(dataLedRXPin, HIGH);
  digitalWrite(errorLedPin, HIGH);
  digitalWrite(startCodeLedPin, HIGH);

  switch (testCounter++) {
    case 0:
      SendProgmemIntFormat(dimmerLEDFormat, testCounter);
      digitalWrite(dimmerLevelOut1LedPin, HIGH);
      break;

    case 1:
      SendProgmemIntFormat(dimmerLEDFormat, testCounter);
      digitalWrite(dimmerLevelOut2LedPin, HIGH);
      break;

    case 2:
      SendProgmemIntFormat(dimmerLEDFormat, testCounter);
      digitalWrite(dimmerLevelOut3LedPin, HIGH);
      break;

    case 3:
      SendProgmemIntFormat(dimmerLEDFormat, testCounter);
      digitalWrite(dimmerLevelOut4LedPin, HIGH);
      break;

    case 4:
      SendProgmemMessage(clockLEDMessage);
      digitalWrite(clockLedRXPin, LOW);
      break;

    case 5:
      SendProgmemMessage(dataLEDMessage);
      digitalWrite(dataLedRXPin, LOW);
      break;

    case 6:
      SendProgmemMessage(errorLEDMessage);
      digitalWrite(errorLedPin, LOW);
      break;

    case 7:
      SendProgmemMessage(startCodeLEDMessage);
      digitalWrite(startCodeLedPin, LOW);
      testCounter = 0;
      break;

    default:
      testCounter = -1;
      return;
      break;
  }

  // Make clock LED track clock input.
  if (!digitalRead(clockInPin)) {
    SendProgmemMessage(clockInMessage);
    digitalWrite(clockLedRXPin, LOW);
  }

  // Make data LED track clock input.
  if (!digitalRead(dataInPin)) {
    SendProgmemMessage(dataInMessage);
    digitalWrite(dataLedRXPin, LOW);
  }
}

/**
 * Run the test sequence for the DMX-TX1.
 */
void TestTransmitterTX1Board() {

  // Skip is not DMX-TX1 or not running a test loop.
  if (testCounter < 0 || detectedBoard != TX1Detected) {
    return;
  }

  // Verify board.
  pinMode(hardwareDetectInputPin, INPUT_PULLUP);
  int isTX1 = digitalRead(hardwareDetectInputPin);

  // Configure IO.
  if (testCounter == 0) {
    pinMode(dimmerSelectButtonPin, INPUT_PULLUP);
    pinMode(clockModeButtonPin, INPUT_PULLUP);
    pinMode(clockStepButtonPin, INPUT_PULLUP);

    pinMode(dataLedTXPin, OUTPUT);
    pinMode(clockLedTXPin, OUTPUT);
    pinMode(dimmerSelect1LedPin, OUTPUT);
    pinMode(dimmerSelect2LedPin, OUTPUT);
    pinMode(dimmerSelect3LedPin, OUTPUT);
    pinMode(dimmerSelect4LedPin, OUTPUT);

    pinMode(dataInPin, INPUT_PULLUP);
    pinMode(clockInPin, INPUT_PULLUP);

    // Verify it's a TX1 before enabling these outputs.
    if (isTX1) {
        pinMode(clockSlowPin, OUTPUT);
        pinMode(clockFastPin, OUTPUT);
    }

    // Use the default analog reference.
    analogReference(DEFAULT);
    int dimmerValue = analogRead(dimmerLevelInputPin);
    int clockValue = analogRead(clockSpeedInputPin);

    // Initialize the buttons.
    dimmerSelectButton.begin();
    clockStepButton.begin();
    clockModeButton.begin();
  }

  // Turn on LEDs in a loop.
  digitalWrite(dimmerSelect1LedPin, HIGH);
  digitalWrite(dimmerSelect2LedPin, HIGH);
  digitalWrite(dimmerSelect3LedPin, HIGH);
  digitalWrite(dimmerSelect4LedPin, HIGH);
  digitalWrite(clockLedTXPin, HIGH);
  digitalWrite(dataLedTXPin, HIGH);
  if (isTX1) {
    digitalWrite(clockFastPin, HIGH);
    digitalWrite(clockSlowPin, HIGH);
  }

  switch (testCounter++) {
    case 0:
      SendProgmemIntFormat(dimmerLEDFormat, testCounter);
      digitalWrite(dimmerSelect1LedPin, LOW);
      break;

    case 1:
      SendProgmemIntFormat(dimmerLEDFormat, testCounter);
      digitalWrite(dimmerSelect2LedPin, LOW);
      break;

    case 2:
      SendProgmemIntFormat(dimmerLEDFormat, testCounter);
      digitalWrite(dimmerSelect3LedPin, LOW);
      break;

    case 3:
      SendProgmemIntFormat(dimmerLEDFormat, testCounter);
      digitalWrite(dimmerSelect4LedPin, LOW);
      break;

    case 4:
      SendProgmemMessage(clockLEDMessage);
      digitalWrite(clockLedTXPin, LOW);
      break;

    case 5:
      SendProgmemMessage(dataLEDMessage);
      digitalWrite(dataLedTXPin, LOW);
      break;

    case 6:
      if (isTX1) {
        SendProgmemMessage(fastLEDMessage);
        digitalWrite(clockFastPin, LOW);
        break;
      }
      // Fallthrough

    case 7:
      if (isTX1) {
        SendProgmemMessage(slowLEDMessage);
        digitalWrite(clockSlowPin, LOW);
        testCounter = 0;
        break;
      }
      // Fallthrough

    default:
      testCounter = -1;
      return;
      break;
  }

  // Look for dimmer and clock mode presses.
  if (isTX1) {

    // If the dimmer select is pressed, light up dimmer LEDs.
    dimmerSelectButton.read();
    if (dimmerSelectButton.isPressed()) {
      SendProgmemMessage(dimmerSelectMessage);
      digitalWrite(dimmerSelect1LedPin, LOW);
      digitalWrite(dimmerSelect2LedPin, LOW);
      digitalWrite(dimmerSelect3LedPin, LOW);
      digitalWrite(dimmerSelect4LedPin, LOW);
    }

    // If the clock step is pressed, light up the slow clock LED.
    clockStepButton.read();
    if (clockStepButton.isPressed()) {
      SendProgmemMessage(clockStepMessage);
      digitalWrite(clockSlowPin, LOW);
    }

    // If the clock mode is pressed, light up the false clock LED.
    clockModeButton.read();
    if (clockModeButton.isPressed()) {
      SendProgmemMessage(clockModeMessage);
      digitalWrite(clockFastPin, LOW);
    }

    // Detect if dimmer level was changed. It bounces around a bit so make sure the change
    // is greater than the a certain threshold.
    dimmerValue = analogRead(dimmerLevelInputPin);
    dimmerValueChange = abs(previousDimmerValue - dimmerValue);
    if (dimmerValueChange >= analogValueThreshold) {
      SendProgmemIntFormat(dimmerValueInFormat, dimmerValue);
      previousDimmerValue = dimmerValue;
    }
  }

  // Detect if clock speed was changed. It bounces around a bit so make sure the change
  // is greater than the a certain threshold.
  int clockValue = analogRead(clockSpeedInputPin);
  int clockValueChange = abs(previousClockValue - clockValue);
  if (clockValueChange >= analogValueThreshold) {
    SendProgmemIntFormat(clockSpeedInFormat, clockValue);
    previousClockValue = clockValue;
  }

  // Make clock LED track clock input.
  if (!digitalRead(clockInPin)) {
    SendProgmemMessage(clockInMessage);
    digitalWrite(clockLedTXPin, LOW);
  }

  // Make data LED track clock input.
  if (!digitalRead(dataInPin)) {
    SendProgmemMessage(dataInMessage);
    digitalWrite(dataLedTXPin, LOW);
  }
}
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

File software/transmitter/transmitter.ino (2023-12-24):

/**
 * DMX Demonstrator Transmitter
 * Copyright (C) 2020 Crazy Giraffe Software
 * https://github.com/crazy-giraffe-software/dmxdemonstrator/tree/master/software/transmitter
 *
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
 * You should have received a copy of the GNU General Public License
 * along with this program.  If not, see <http://www.gnu.org/licenses/>.
 */

/**
 * About DMX Demonstrator Transmitter
 *
 * This software supports the Arduio-based DMX Demonstrator Transmitter
 * running any of the supported hardware options.
 */
#define _VERSION_ "1.2"

/**
 * Local copy of JC_Button: https://github.com/JChristensen/JC_Button
 * This avoids having to add it as an explicit library.
 */
#include "JC_Button.h"

/**
 * A local include for asynchronous analog sampling. Note that this function is not
 * compatible with analogRead() because it allows a sample to be started without
 * requiring it to finish while analogRead() will always finish a sample and therefore
 * always assumes a sample is not in progress. analogRead() can be used but care must
 * be used to ensure analogRead() and analogReadAsync() are not interleaved.
 */
#include "AnalogAsync.h"

/**
 * Include timer abstractions
 */
#include "AdjustableTimer1.h"
#include "FixedTimer2.h"

/**
 * Pin definitions.
 */
int currentDimmerLevelInputPin = A0;     // The single dimmer level control for the DMX-TX1.
int currentDimmerLevel1InputPin = A0;    // The dimmer 1 level control for the DMX-TX2/DMX-CPB.
int currentDimmerLevel2InputPin = A1;    // The dimmer 2 level control for the DMX-TX2/DMX-CPB.
int currentSelectedDimmerButtonPin = A1; // The dimmer select button for the DMX-TX1.
int currentDimmerLevel3InputPin = A2;    // The dimmer 3 level control for the DMX-TX2/DMX-CPB.
int clockModeButtonPin = A2;             // The clock mode button for the DMX-TX1.
int currentDimmerLevel4InputPin = A3;    // The dimmer 4 level control for the DMX-TX2/DMX-CPB.
int clockSpeedInputPin = A4;             // The clock speed control for both the DMX-TX1 and DMX-TX2/DMX-CPB.
int clockStepButtonPin = A5;             // The clock step button for the DMX-TX1.

int dataLedPin = 2;                      // The data led output for both the DMX-TX1 and DMX-TX2/DMX-CPB.
int clockLedPin = 3;                     // The clock led output for both the DMX-TX1 and DMX-TX2/DMX-CPB.
int currentSelectedDimmer4LedPin = 4;    // The dimmer select 4 led output for the DMX-TX1.
int currentSelectedDimmer3LedPin = 5;    // The dimmer select 3 led output for the DMX-TX1.
int currentSelectedDimmer2LedPin = 6;    // The dimmer select 2 led output for the DMX-TX1.
int currentSelectedDimmer1LedPin = 7;    // The dimmer select 1 led output for the DMX-TX1.
int clockFastIOPin = 8;                  // The clock speed fast out for the DMX-TX1, in for the DMX-TX2/DMX-CPB.
int clockSlowIOPin = 9;                  // The clock speed slow out for the DMX-TX1, in for the DMX-TX2/DMX-CPB.
int hardwareDetectOutPin = 10;           // Output to indicate which transmitter board is connected, LOW for DMX-TX2.
int hardwareDetectInPin = 11;            // Input to determine which transmitter board is connected, LOW for DMX-TX2.
int dataOutPin = 12;                     // The data output to the receiver.
int clockOutPin = 13;                    // The clock output to the receiver.

/**
 * Switches.
 */
Button currentSelectedDimmerButton = Button(currentSelectedDimmerButtonPin);
Button clockStepButton = Button(clockStepButtonPin);
Button clockModeButton = Button(clockModeButtonPin);
Button clockSlowButton = Button(clockSlowIOPin);
Button clockFastButton = Button(clockFastIOPin);

/**
 * Hardware detect data.
 */
int usingControlPro = 0;

const char hardwareDetectFormat[] PROGMEM = "Hardware Detection: found %s\r\n";
const char hardwareDetectTX1[] PROGMEM = "DMX-TX1";
const char hardwareDetectTX2[] PROGMEM = "DMX-TX2/DMX-CPB";
const char* const hardwareDetectMessages[] PROGMEM = { hardwareDetectTX1, hardwareDetectTX2, };

/**
 * Analog capture data.
 */
volatile int analogCaptureChannel = -1; // O = Clock, 1-4 = dimmers

/**
 * Clock mode & speed data.
 */
const long clockFastFrequency = 3000;
const long clockSlowMaxFrequency = 200;
const long clockSlowMinFrequency = 1;
const long clockOffFrequency = 2;

int currentClockMode = -1;
const int clockModeOff = 0;
const int clockModeSlow = 1;
const int clockModeFast = 2;
const int clockModeToggle = 255;
volatile int clockValue = 0;
int clockValueThreshold = 5;

const char setClockResponseFormat[] PROGMEM = "Set clock mode: %s\r\n";
const char clockModeOffMessage[] PROGMEM = "Off";
const char clockModeFastMessage[] PROGMEM = "Fast";
const char clockModeSlowMessage[] PROGMEM = "Slow";
const char* const clockModeMessages[] PROGMEM = { clockModeOffMessage, clockModeSlowMessage, clockModeFastMessage, };

/**
 * Dimmer select data.
 */
int currentSelectedDimmer = 0;
const int selectedDimmerToggle = 255;
volatile int currentDimmerLevels[4] = { 0 };

const char setDimmerResponseFormat[] PROGMEM = "Set dimmer: %d\r\n";

/**
 * Message for frame steps.
 */
char* null = 0;
const char frameBreakFormat[] PROGMEM = "Frame Break (%d)";
const char markAfterBreakFormat[] PROGMEM = "Mark after Break (%d)";
const char startCodeStartBitMessage[] PROGMEM = "Start code Start bit";
const char startCodeFormat[] PROGMEM = "Start code data bit %d";
const char dimmer1StartBitMessage[] PROGMEM = "Dimmer 1 Start bit";
const char dimmer1DataFormat[] PROGMEM = "Dimmer 1 data bit %d";
const char dimmer2StartBitMessage[] PROGMEM = "Dimmer 2 Start bit";
const char dimmer2DataFormat[] PROGMEM = "Dimmer 2 data bit %d";
const char dimmer3StartBitMessage[] PROGMEM = "Dimmer 3 Start bit";
const char dimmer3DataFormat[] PROGMEM = "Dimmer 3 data bit %d";
const char dimmer4StartBitMessage[] PROGMEM = "Dimmer 4 Start bit";
const char dimmer4DataFormat[] PROGMEM = "Dimmer 4 data bit %d";
const char dataMarkFormat[] PROGMEM = "Mark (%d)";
const char frameMarkMessage[] PROGMEM = "Mark between Frames";
const char endFrameMessage[] PROGMEM = "End of Frame";

const char invalidFrameStepFormat[] PROGMEM = "Invalid frame step: %d";
const char frameStepFormat[] PROGMEM = "Step: %2d\t";
const char dataOutBitFormat[] PROGMEM = "Data: %d\t\t";
const char dimmerDataFormat[] PROGMEM = ", level: %3dd, %02Xh, %d%d%d%d%d%d%d%db";
const char dimmerCaptureFormat[] PROGMEM = ", Dimmer %d capture";

/**
 * Variables for sending a frame of data.
 */
int currentFrameStep = -1;
int frameStepCount = 88;
volatile int dataOutBit = 0;
volatile int clockOutBit = LOW;
volatile int currentDimmerLevel = 0;
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

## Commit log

2020-09-26 Initial 1.0 version of transmitter.
    [transmitter.kicad_pcb, transmitter.sch]
2020-09-26 Initial 1.0 version of receiver.
    [receiver.kicad_pcb, receiver.sch]
2020-09-26 Initial 1.0 version of display-pro.
    [display-pro.kicad_pcb, display-pro.sch]
2020-09-26 Initial 1.0 version of control-pro.
    [control.kicad_pcb, control.sch, faceplate.kicad_pcb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]
2020-09-27 Add parts lists. Add PCB links. Fix silkscreen of connector J2 on DMX-TX2.
    [transmitter.kicad_pcb]
2020-09-27 Enlarged 3rd slider slot width to remove copper from faceplate.
    [faceplate.kicad_pcb, faceplate.sch]
2020-09-29 Add rounded corners to control-pro.
    [control.kicad_pcb, control.sch, faceplate.kicad_pcb]
2020-11-08 Rev 1.1: - Fixed arduino shield footprint (it was backwards) - Added Fcu power plane - New Fcu layouts - Added rounded corners
    [display-pro.kicad_pcb, receiver.kicad_pcb, receiver.sch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]
2020-11-09 Remove coax power jack from display-pro; the Sparkfun footprint does not nest inside the 2 pin connector so only providing that option.
    [display-pro.kicad_pcb, display-pro.sch]
2022-09-14 Users/sparky/txrx12 (#11)
    * TX1 1.2, RX1 1.2
    Move Clock LED to avoid ICSP connector.
    Align TX Fast/Slo clock LEDS and RX start code/error LEDs.
    * Add RXCLK to D9 connection for Leonardo PCINT5.
    [receiver.kicad_pcb, receiver.sch, transmitter.kicad_pcb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]
2023-02-08 Users/sparky/rx refactor (#12)
    * Refactor Receiver, V1.1
    * Move serial transmission out of the clock interrupt
    * Move pin change code to libraries
    * Add verbose and compact status modes
    * Make variable naming consistent
    * Make comment style consistent
    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
2023-02-08 Users/sparky/tx refactor (#13)
    * Refactor Transmitter, V1.1
    * Move timer code to libraries
    * Include JC_Button as a local library to make the code self-contained
    * Implement async analog capture
    * Add files for VS Code Arduino extension
    * Standardize on "step".
    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
2023-02-08 Add discovery sketch to determine attached board and test it. (#14)
2023-02-09 Fixes: (#15)
    - Slow down analog read clock
    - Fix bug on TX1 where dimmer value was written to all dimmers, not the selected dimmer
    - Fix bug where clock speed was using byte math instead of long math due to #define
    - Avoid going into error state when stream is in break at expected time
    - Disable verbose mode when the clock is too fast to keep up with writing the verbose output
    [receiver.ino, transmitter.ino]
2023-12-23 Ignore gerber files.
2023-12-24 Final tweaks to TX1 and RX1 based on construction. (#17)
    * Improve surface areea of power plane.
    * Add design badges
    Remove PWM connect from RX1
    Update TX1 board details
    commit 6da493b019dfdde530e2737d5f7a25deacfc908e
    Author: SparkyBobo <sparky@crazygiraffesoftware.com>
    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
    [receiver.kicad_pcb, receiver.sch, transmitter.kicad_pcb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]
2023-12-24 Users/sparky/control pro v1.3 (#18)
    * DMX-TX2 V1.1:
    - Fixed shield footprint
    - Moved Clock LED to avoid Arduino ICSP connector.
    - Relabeled the clock fast and slow LED connections in the
    schematic to match the board layout.
    - Added Fcu power plane
    - Redid Fcu layout
    - Added rounded corners
    * Refactor Control-Pro:
    - Rename all dimmers to dim1-4 (instead of dim0-3)
    - Split control-pro into 2 smaller board to save on board cost
    - clock-control/faceplate only has clock controls
    - dimmer-control/faceplate only has dimmer controls
    - both control-pro boards have 2 ribbon cable connectors
    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
    [clock-control.kicad_pcb, clock-control.sch, clock-faceplate.kicad_pcb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]
2024-02-18 Add mini mover files.
    [mini-mover-driver.kicad_pcb, mini-mover-driver.sch]

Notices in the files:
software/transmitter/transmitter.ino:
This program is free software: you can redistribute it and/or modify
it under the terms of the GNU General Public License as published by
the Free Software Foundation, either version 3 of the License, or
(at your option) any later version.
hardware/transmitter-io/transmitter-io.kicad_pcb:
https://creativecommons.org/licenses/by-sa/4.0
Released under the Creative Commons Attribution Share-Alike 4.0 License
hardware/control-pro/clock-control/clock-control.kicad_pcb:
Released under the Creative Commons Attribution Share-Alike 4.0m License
